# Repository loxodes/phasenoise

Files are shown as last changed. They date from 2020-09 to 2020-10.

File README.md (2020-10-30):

# low(ish) phase noise downconverter 
* 10-6000 MHz RF
* DC-1MHz IF
* Internal LO generation, phase locked to RF input
* Designed to fit on the J40 header of Lattice ECP5 EVN eval board

Software development and hardware testing is in progress.
The only documentation is the [schematic](./phase_noise_downconver_schematic_2020_10.pdf).

## Usage
This project is under development, y'all probably don't want to try reproducing it yet.

## License
Unless otherwise noted, all work is under a MIT license.

## Contact
Feel free to contact me at arcticmicrowave@gmail.com or loxodes on irc.freenode.net

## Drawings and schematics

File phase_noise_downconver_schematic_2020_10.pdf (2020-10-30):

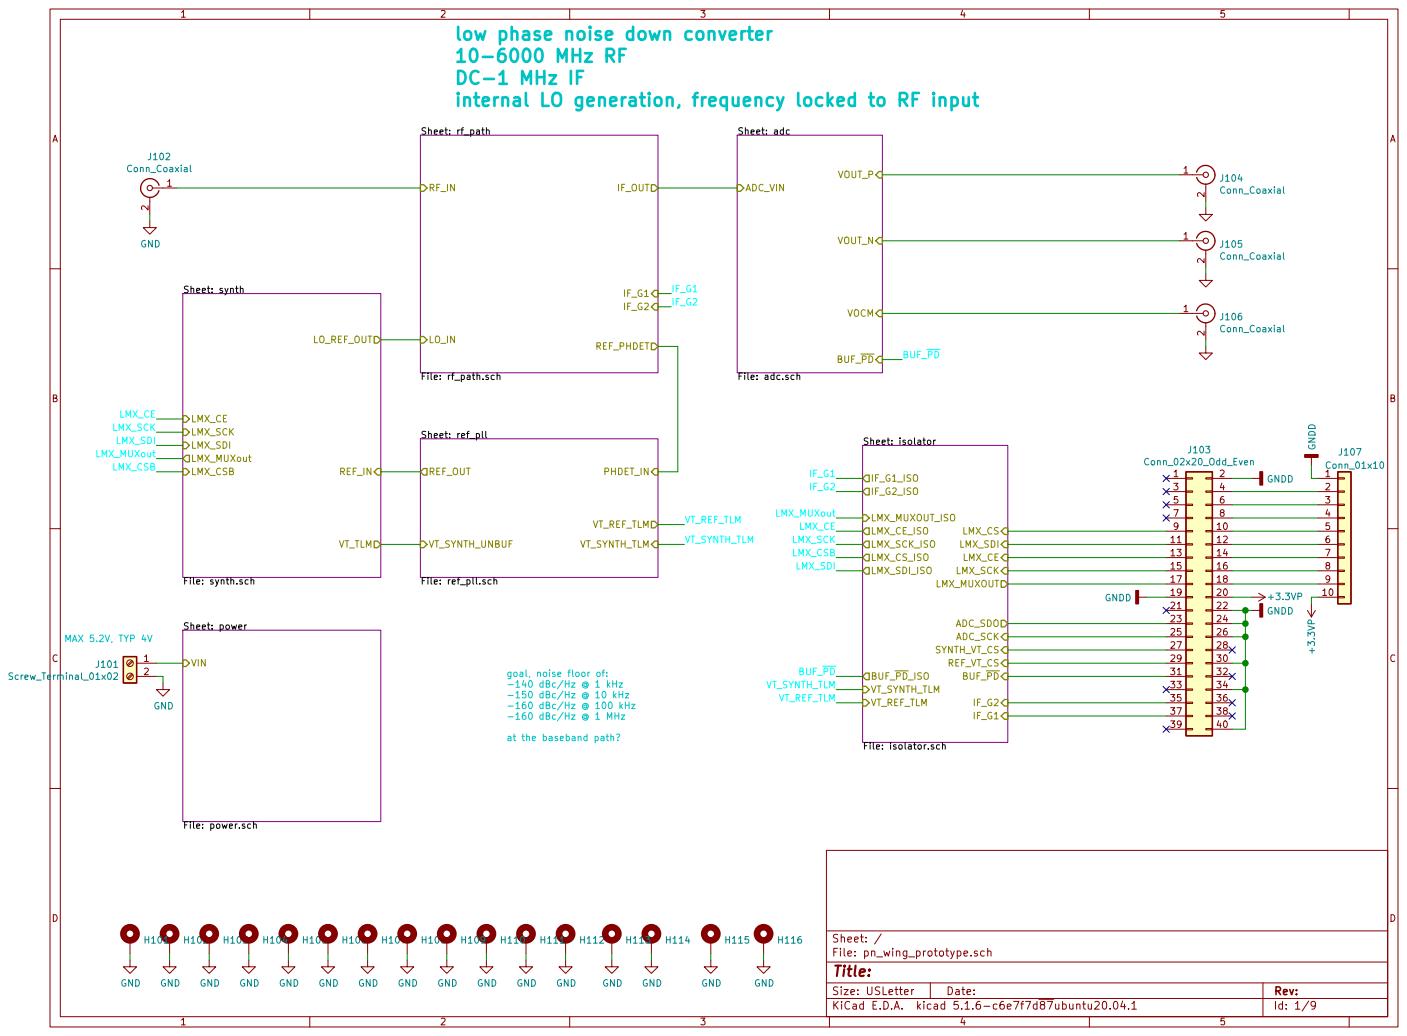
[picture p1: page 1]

low phase noise down converter
10-6000 MHz RF
DC-1 MHz IF

internal LO generation, frequency locked to RF input MAX 5.2V, TYP 4V

Sheet: adc File: adc.sch ADC_VIN

11 | 12 6
13 | 14 7
15 | 16 8
17 | 18 9

File: pn_wing_prototype.sch Sheet: / Sheet: power
File: power.sch VIN

25 | 26
27 | 28 30

goal, noise floor of: -140 dBc/Hz @ 1 kHz

-150 dBc/Hz @ 10 kHz
-160 dBc/Hz @ 100 kHz
-160 dBc/Hz @ 1 MHz at the baseband path?

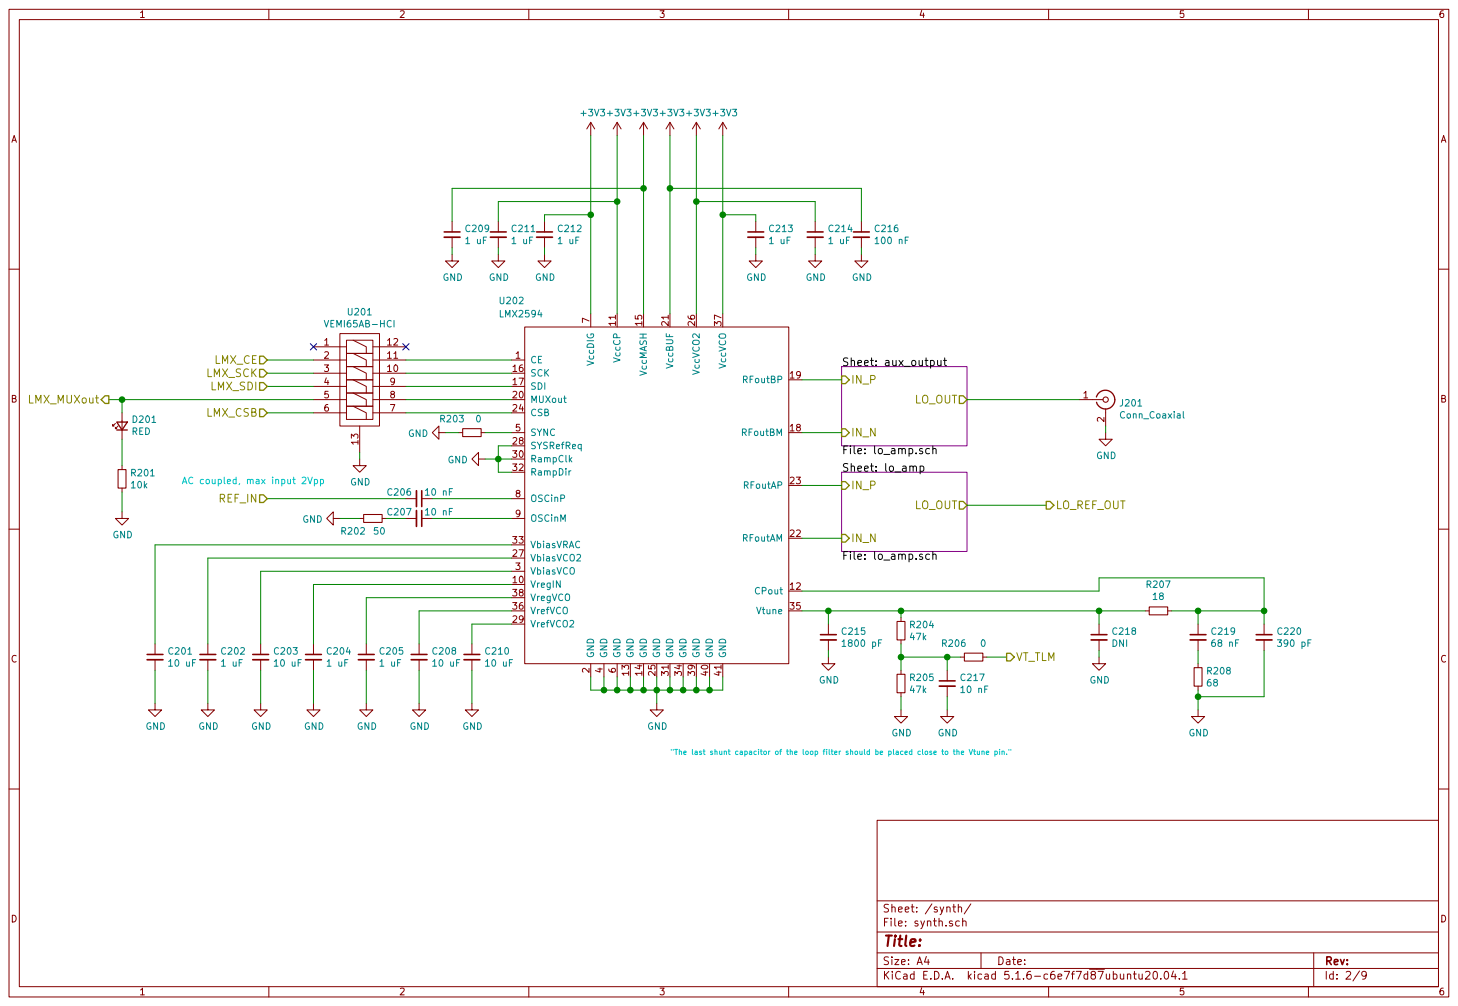
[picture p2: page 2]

2 MUXout 20 VccBUF 21 RFoutAM 22 RFoutAP 23 CSB 24 GND 25 VccVCO2 26 VbiasVCO2 27 SYSRefReq 28 VrefVCO2 29 VbiasVCO 3 RampClk 30 GND 31 RampDir 32 VbiasVRAC 33 GND 34 Vtune 35 VrefVCO 36 VccVCO 37

4 GND 40 GND 41 SYNC 5 GND

AC coupled, max input 2Vpp

"The last shunt capacitor of the loop filter should be placed close to the Vtune pin."

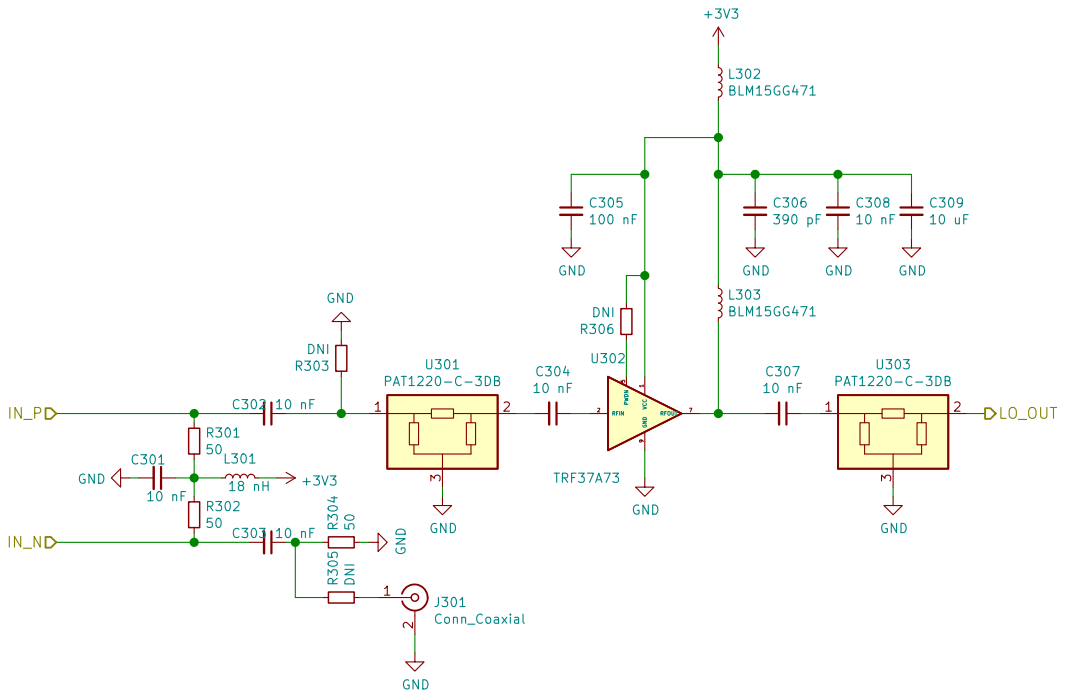
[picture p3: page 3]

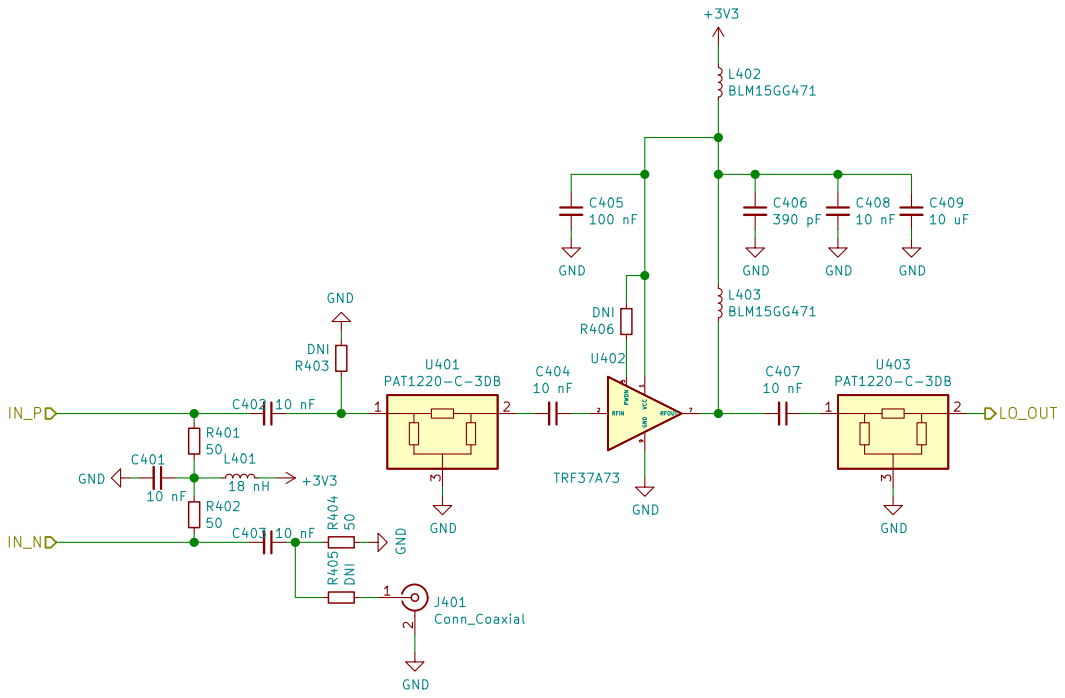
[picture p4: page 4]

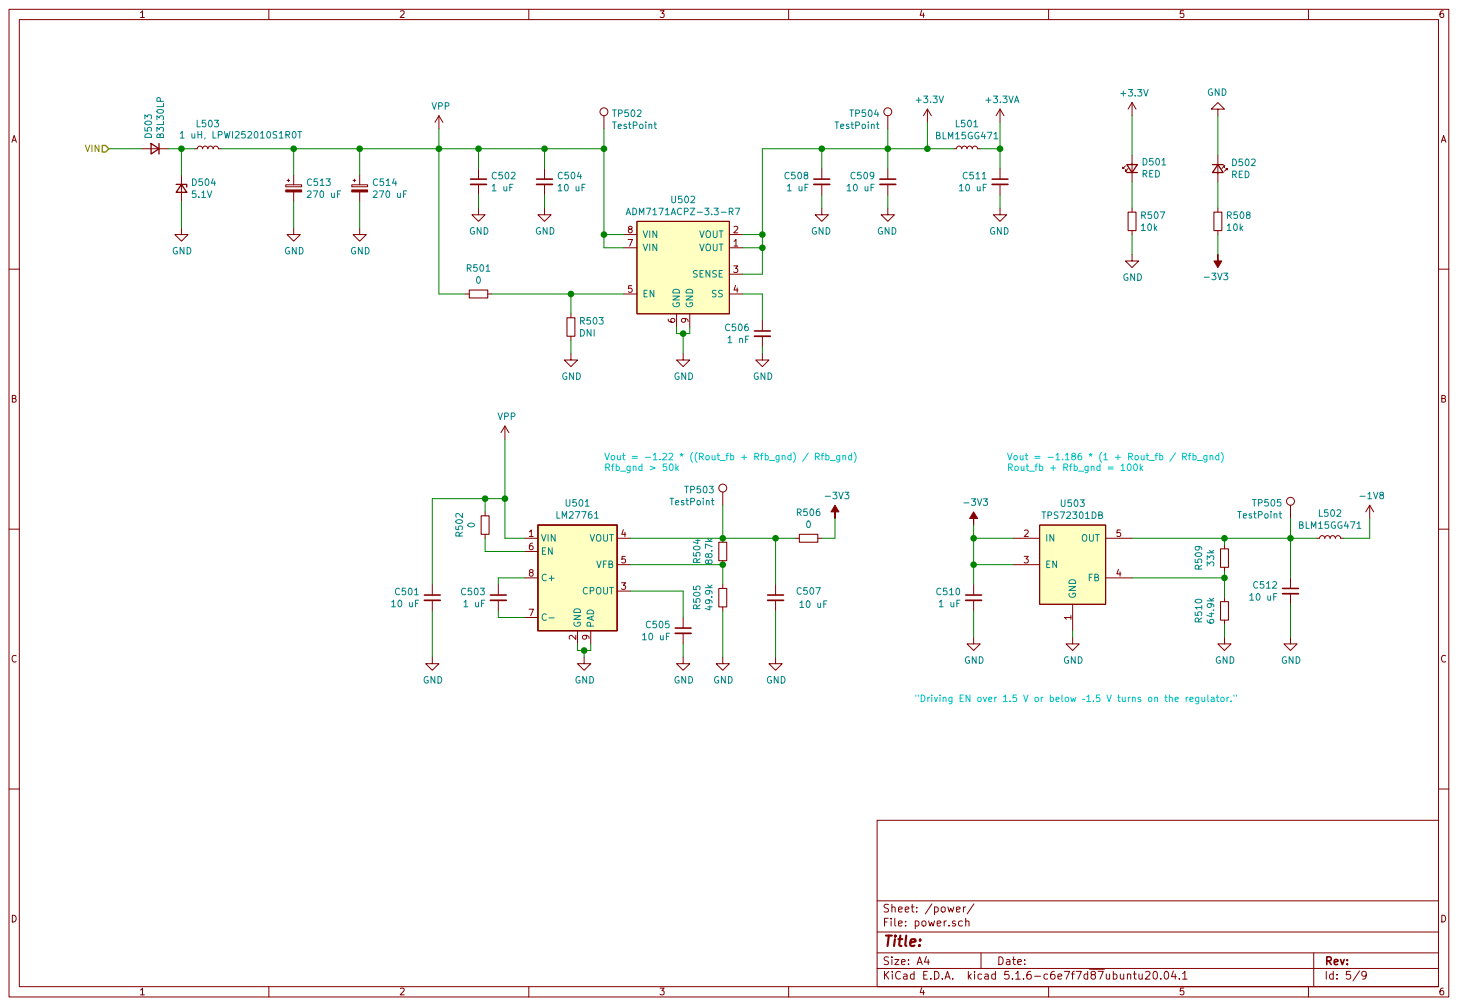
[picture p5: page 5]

2 CPOUT 3 VOUT 4 VFB 5 EN 6 C- 7 C+ 8 PAD

"Driving EN over 1.5 V or below 1.5 V turns on the regulator."

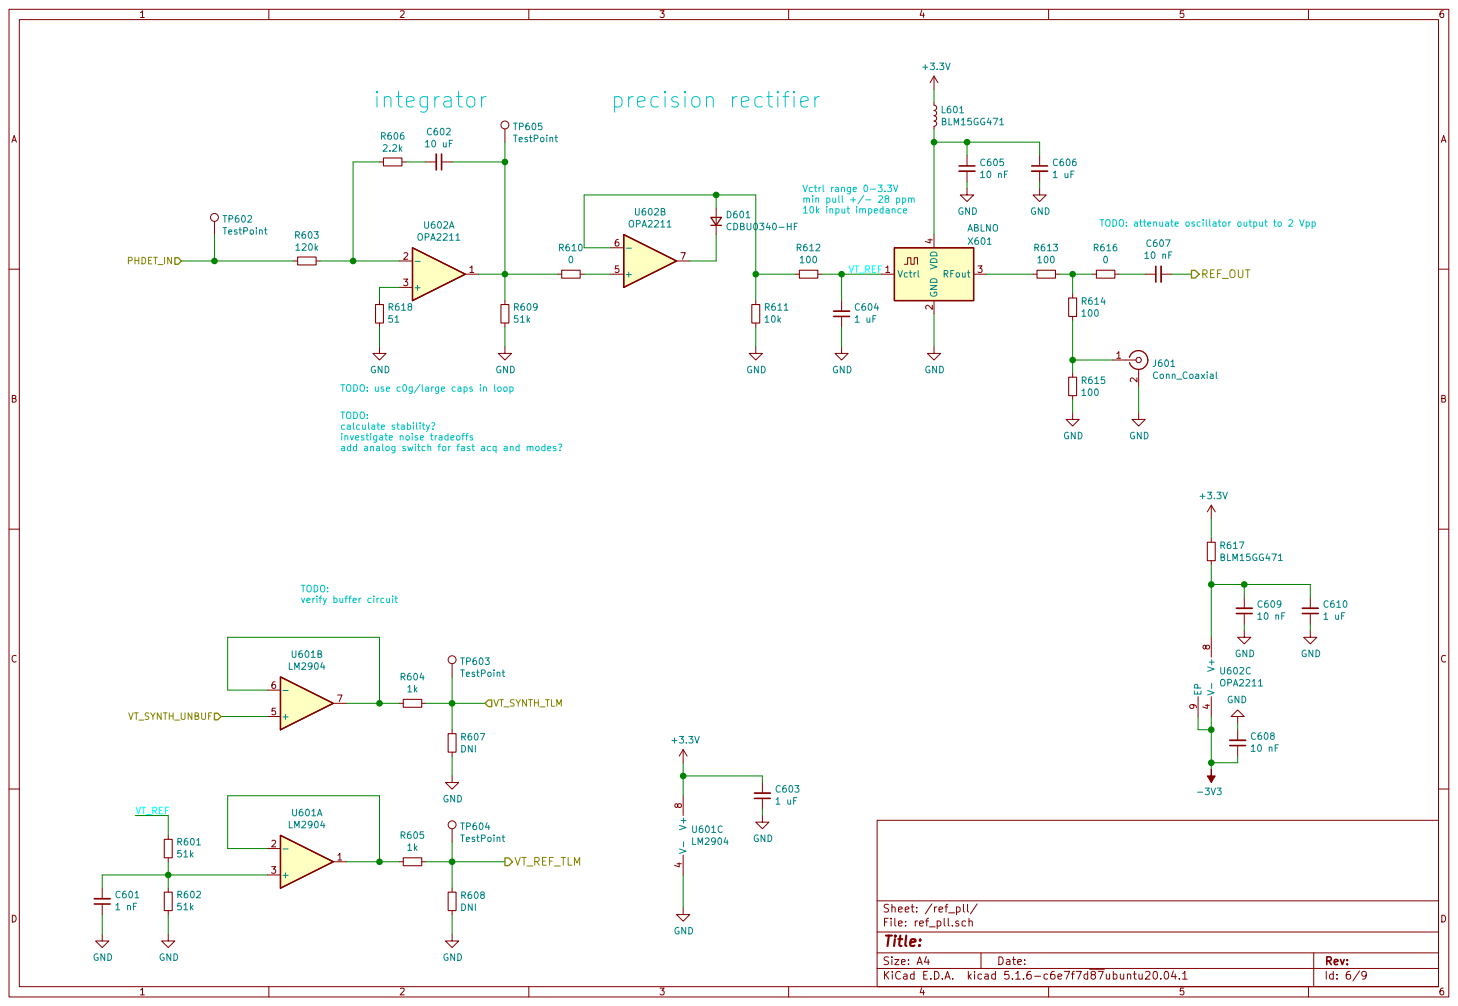
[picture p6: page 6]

10k input impedance TODO: verify buffer circuit TODO: calculate stability?

TODO: attenuate oscillator output to 2 Vpp

TODO: use c0g/large caps in loop

investigate noise tradeoffs
add analog switch for fast acq and modes?

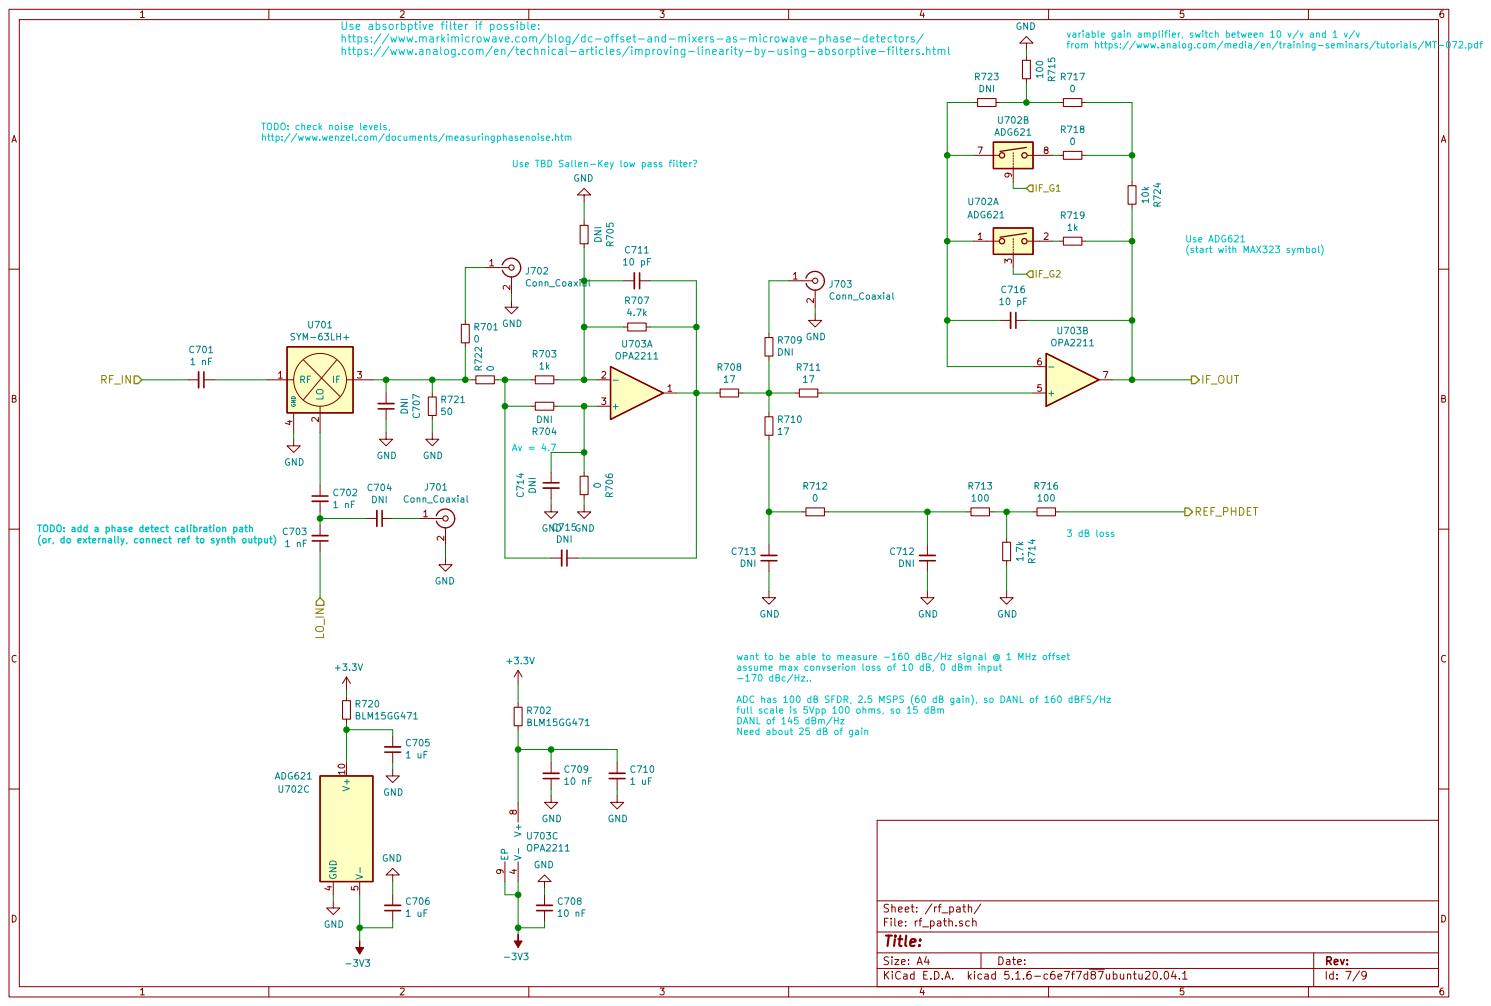
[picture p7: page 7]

IF_G2 Use absorbptive filter if possible:
https://www.markimicrowave.com/blog/dc-offset-and-mixers-as-microwave-phase-detectors/

variable gain amplifier, switch between 10 v/v and 1 v/v

https://www.analog.com/en/technical-articles/improving-linearity-by-using-absorptive-filters.html TODO: check noise levels, http://www.wenzel.com/documents/measuringphasenoise.htm

Use TBD Sallen-Key low pass filter?

DANL of 145 dBm/Hz Need about 25 dB of gain Av = 4.7

TODO: add a phase detect calibration path
(or, do externally, connect ref to synth output)

want to be able to measure -160 dBc/Hz signal @ 1 MHz offset
assume max convserion loss of 10 dB, 0 dBm input -170 dBc/Hz.. ADC has 100 dB SFDR, 2.5 MSPS (60 dB gain), so DANL of 160 dBFS/Hz

full scale is 5Vpp 100 ohms, so 15 dBm

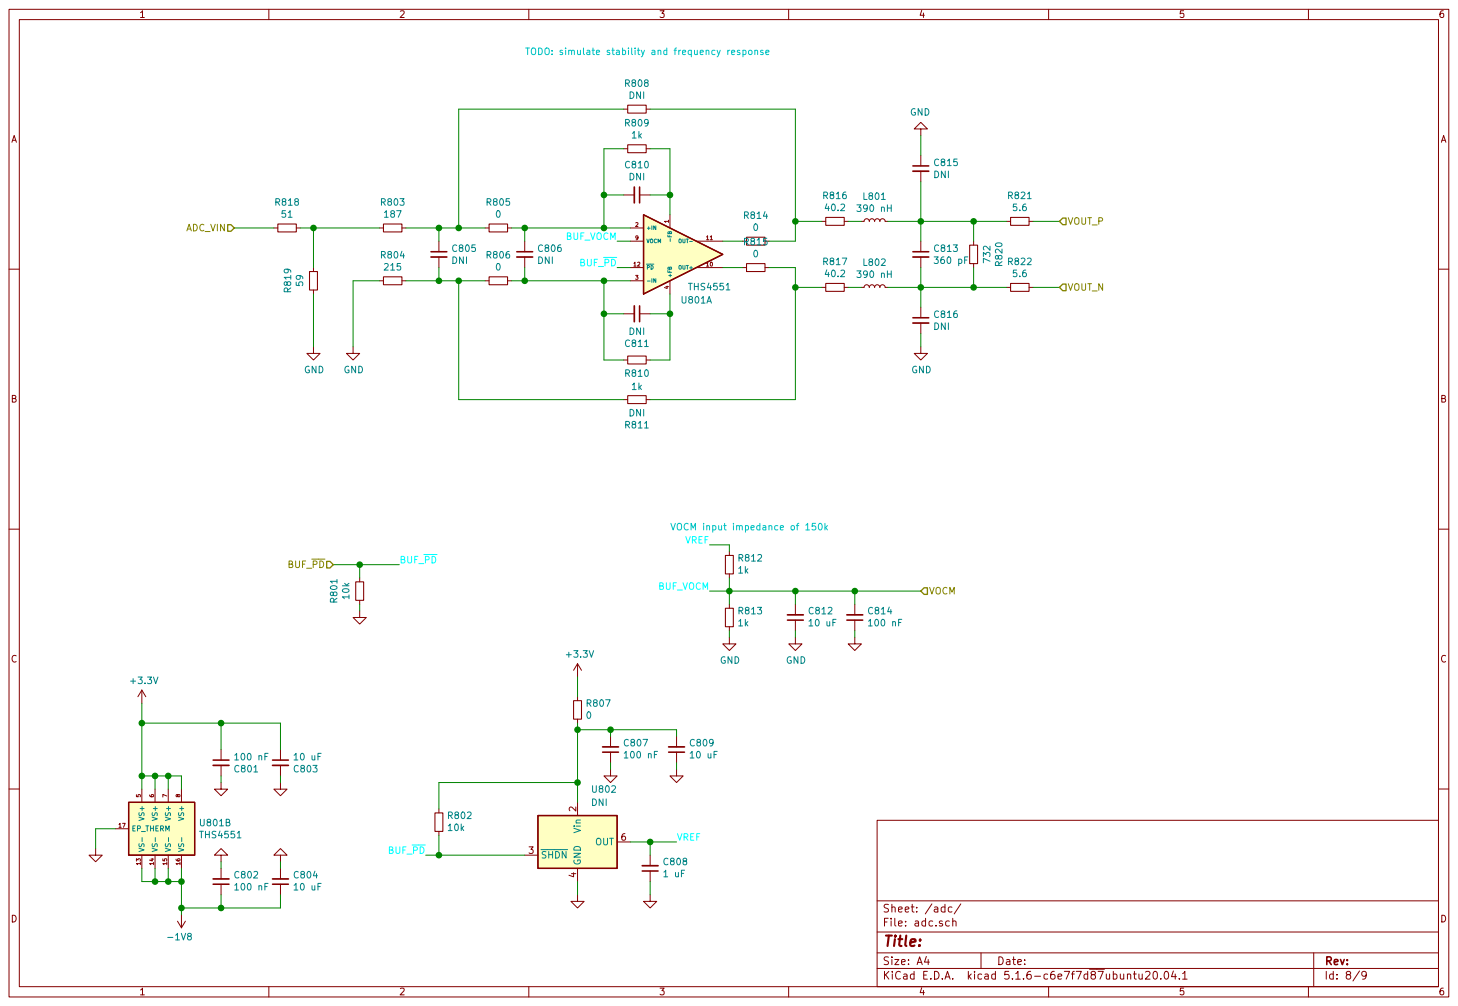
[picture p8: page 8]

TODO: simulate stability and frequency response
1 uF R811 DNI C811 DNI R804

VOCM input impedance of 150k

Id: 8/9 Title: File: adc.sch Sheet: /adc/

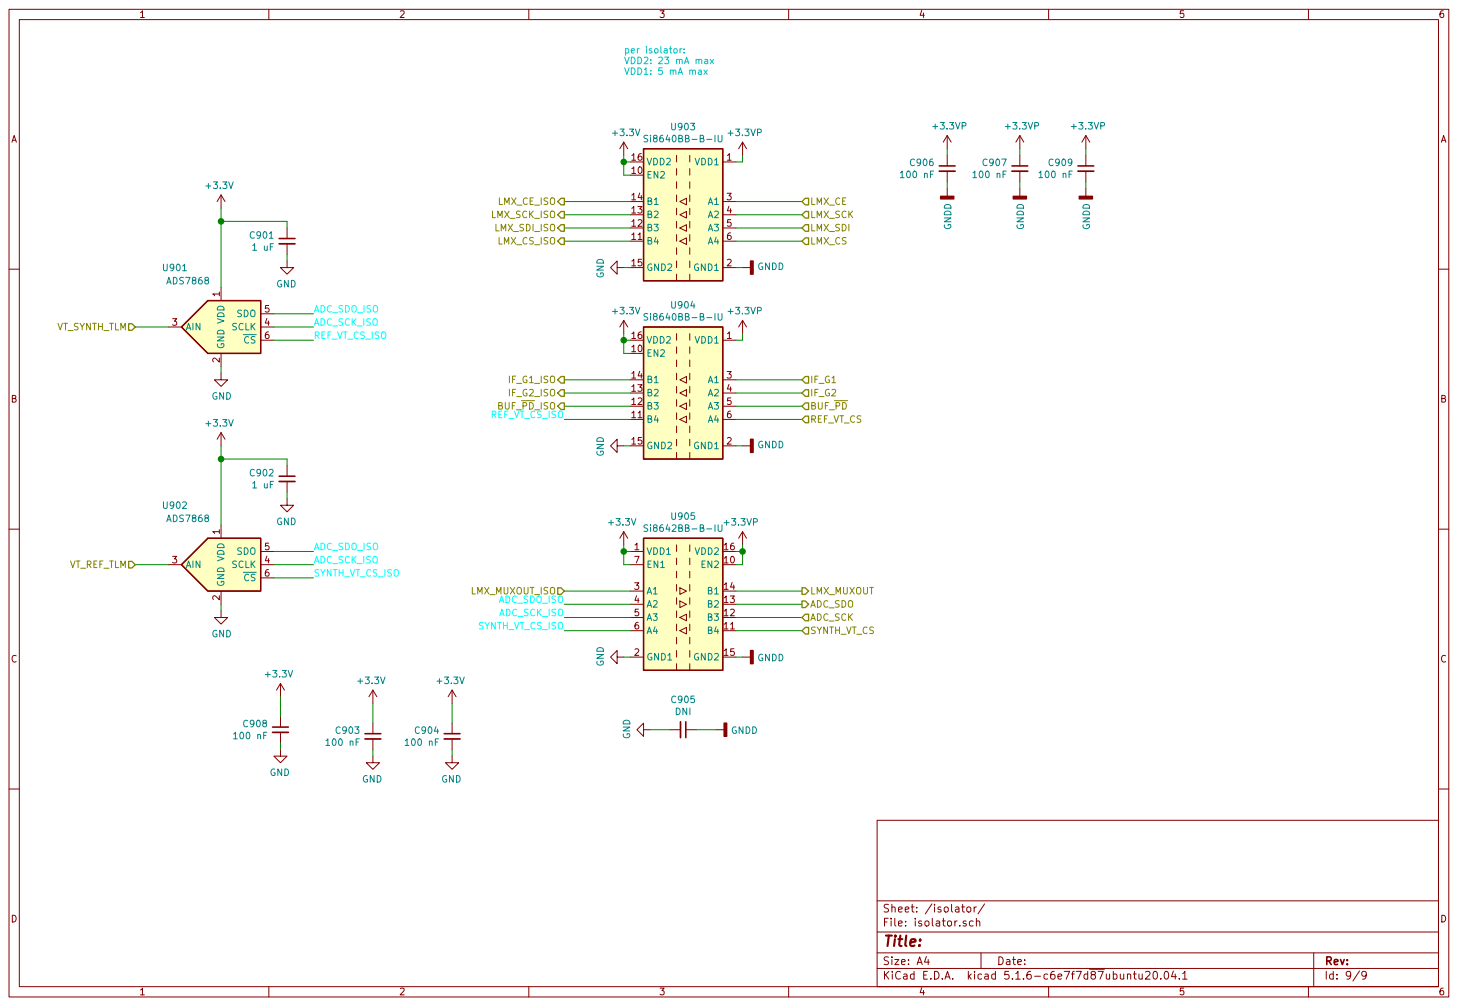
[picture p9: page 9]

per isolator: VDD2: 23 mA max VDD1: 5 mA max
100 nF VDD

2 AIN 3 SCLK 4 SDO 5 CS 6 U901 ADS7868 GND

2 AIN 3 SCLK 4 SDO 5 CS 6 U902 ADS7868 GND GND

Id: 9/9 Title: File: isolator.sch Sheet: /isolator/ GND

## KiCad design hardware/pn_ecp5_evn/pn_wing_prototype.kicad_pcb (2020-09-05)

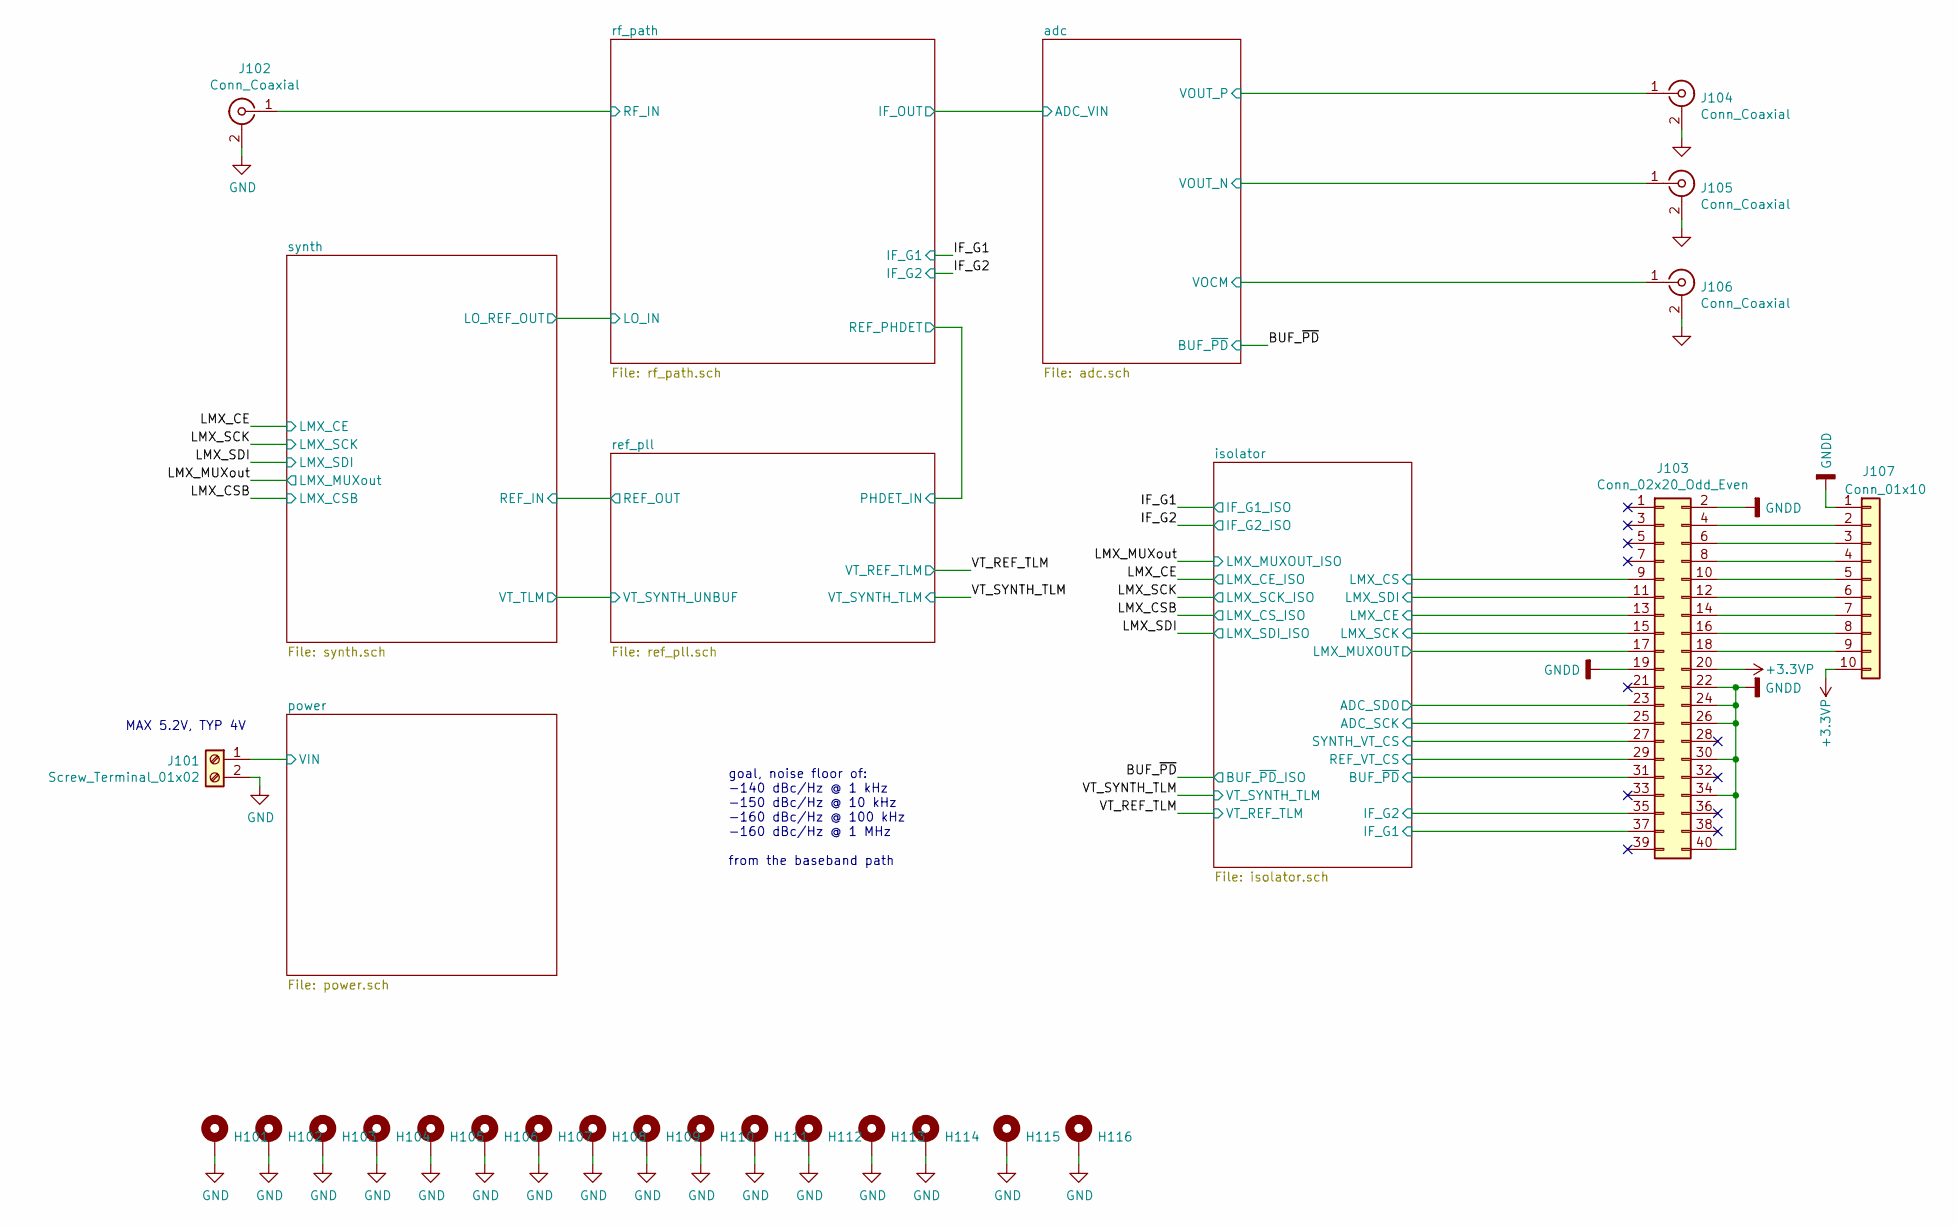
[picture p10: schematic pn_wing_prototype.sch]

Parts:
H101, H102, H103, H104, H105, H106, H107, H108, H109, H110, H111, H112, H113, H114, H115, H116: MountingHole_Pad; MountingHole_2.7mm_M2.5_ISO14580_Pad
J101: Screw_Terminal_01x02; TerminalBlock_Phoenix_MPT-0,5-2-2.54_1x02_P2.54mm_Horizontal
J102, J104, J105, J106: Conn_Coaxial; SMA_Molex_73251-1153_OSHFR408
J103: Conn_02x20_Odd_Even; PinSocket_2x20_P2.54mm_Vertical
J107: Conn_01x10; PinHeader_1x10_P2.54mm_Vertical

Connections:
+3.3VP: J103.20, J107.10; also elsewhere on the board
/adc/VOCM: J106.1 (In); also elsewhere on the board
/adc/VOUT_N: J105.1 (In); also elsewhere on the board
/adc/VOUT_P: J104.1 (In); also elsewhere on the board
/isolator/ADC_SCK: J103.25; also elsewhere on the board
/isolator/ADC_SDO: J103.23; also elsewhere on the board
/isolator/BUF_~PD: J103.31; also elsewhere on the board
/isolator/IF_G1: J103.37; also elsewhere on the board
/isolator/IF_G2: J103.35; also elsewhere on the board
/isolator/LMX_CE: J103.13; also elsewhere on the board
/isolator/LMX_CS: J103.9; also elsewhere on the board
/isolator/LMX_MUXOUT: J103.17; also elsewhere on the board
/isolator/LMX_SCK: J103.15; also elsewhere on the board
/isolator/LMX_SDI: J103.11; also elsewhere on the board
/isolator/REF_VT_CS: J103.29; also elsewhere on the board
/isolator/SYNTH_VT_CS: J103.27; also elsewhere on the board
/power/VIN: J101.1; also elsewhere on the board
/rf_path/RF_IN: J102.1 (In); also elsewhere on the board
GND: H101.1, H102.1, H103.1, H104.1, H105.1, H106.1, H107.1, H108.1, H109.1, H110.1, H111.1, H112.1, H113.1, H114.1, H115.1, H116.1, J101.2, J102.2 (Ext), J104.2 (Ext), J105.2 (Ext), J106.2 (Ext); also elsewhere on the board
GNDD: J103.2, J103.19, J103.22, J103.24, J103.26, J103.30, J103.34, J103.40, J107.1; also elsewhere on the board
unnamed: J103.4, J107.2
unnamed: J103.6, J107.3
unnamed: J103.8, J107.4
unnamed: J103.10, J107.5
unnamed: J103.12, J107.6
unnamed: J103.14, J107.7
unnamed: J103.16, J107.8
unnamed: J103.18, J107.9

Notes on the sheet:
goal, noise floor of: -140 dBc/Hz @ 1 kHz -150 dBc/Hz @ 10 kHz -160 dBc/Hz @ 100 kHz -160 dBc/Hz @ 1 MHz from the baseband path
MAX 5.2V, TYP 4V

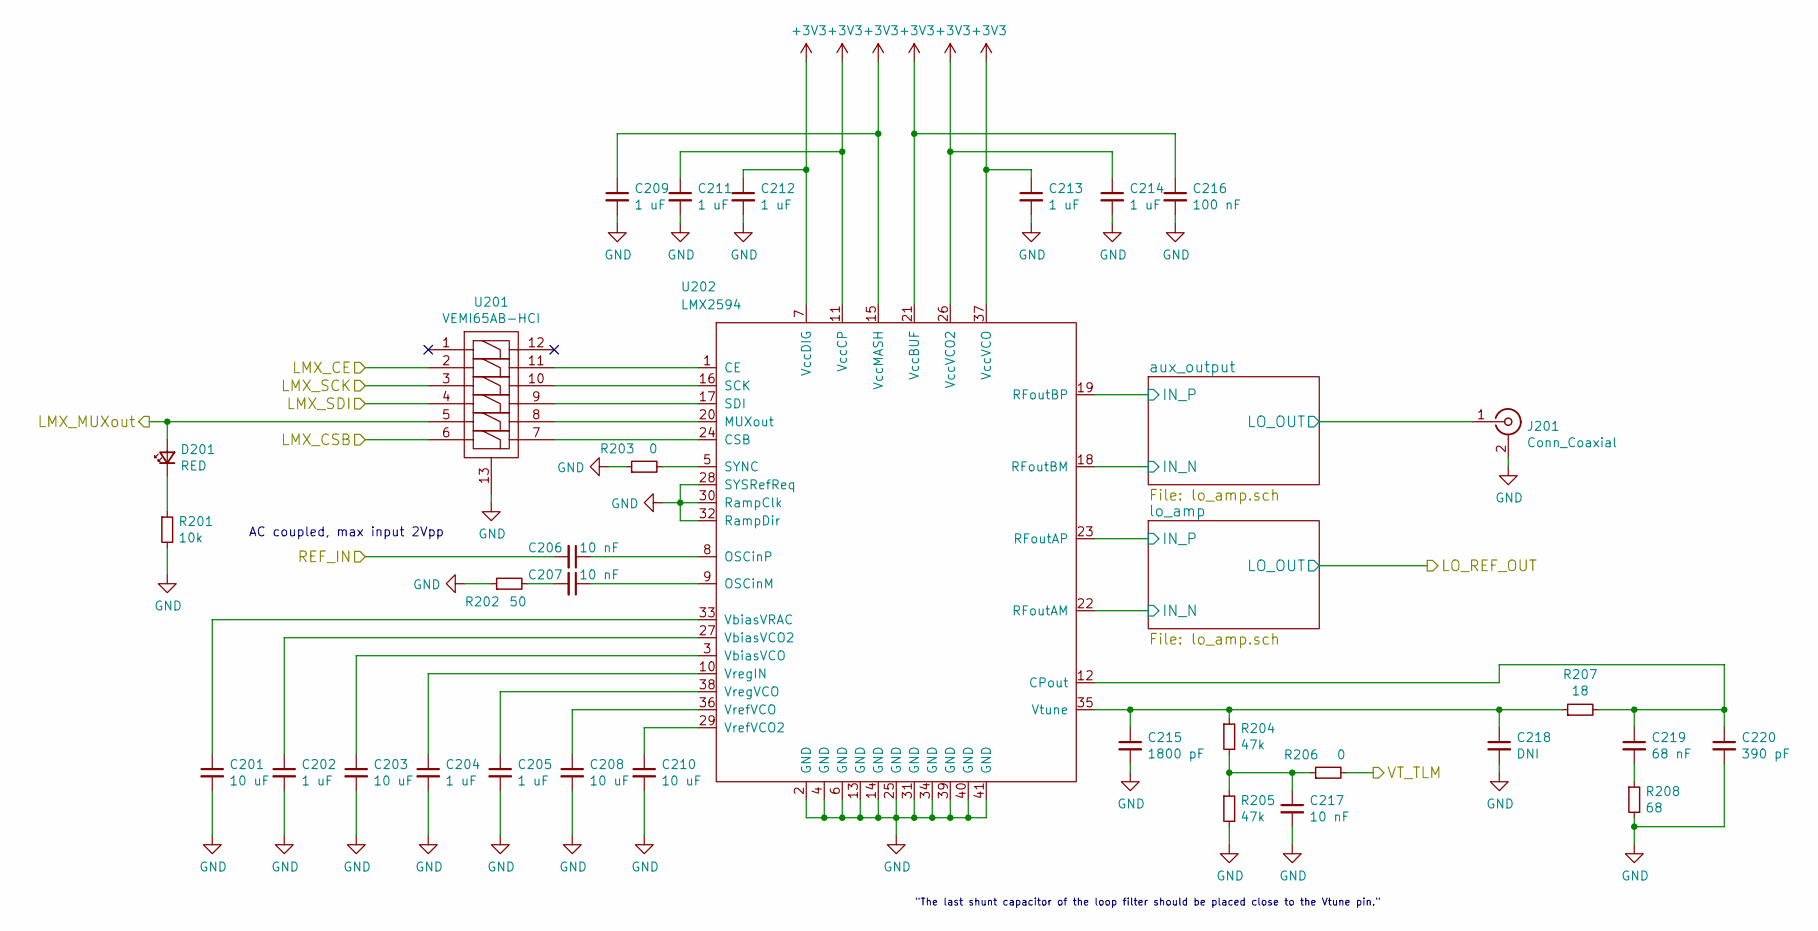
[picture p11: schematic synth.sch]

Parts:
C201, C203, C208, C210: 10 uF; C_0603_1608Metric
C202, C204, C205, C209, C211, C212, C213, C214: 1 uF; C_0402_1005Metric
C206, C207, C217: 10 nF; C_0402_1005Metric
C215: 1800 pF; C_0402_1005Metric
C216: 100 nF; C_0402_1005Metric
C218: DNI; C_0603_1608Metric
C219: 68 nF; C_0603_1608Metric
C220: 390 pF; C_0603_1608Metric
D201: RED; LED_0603_1608Metric
J201: Conn_Coaxial; SMA_Molex_73251-1153_OSHFR408
R201: 10k; R_0402_1005Metric
R202: 50; R_0402_1005Metric
R203, R206: 0; R_0402_1005Metric
R204, R205: 47k; R_0402_1005Metric
R207: 18; R_0402_1005Metric
R208: 68; R_0402_1005Metric
U201: VEMI65AB-HCI; LLP2513-13L
U202: LMX2594; Texas_S-PVQFN-N40_EP4.6x4.6mm

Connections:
/LMX_CE: U201.2; also elsewhere on the board
/LMX_CSB: U201.6; also elsewhere on the board
/LMX_MUXout: D201.2 (A), U201.5; also elsewhere on the board
/LMX_SCK: U201.3; also elsewhere on the board
/LMX_SDI: U201.4; also elsewhere on the board
/ref_pll/VT_SYNTH_UNBUF: R206.2; also elsewhere on the board
/synth/REF_IN: C206.2; also elsewhere on the board
/synth/aux_output/IN_N: U202.18 (RFoutBM); also elsewhere on the board
/synth/aux_output/IN_P: U202.19 (RFoutBP); also elsewhere on the board
/synth/aux_output/LO_OUT: J201.1 (In); also elsewhere on the board
/synth/lo_amp/IN_N: U202.22 (RFoutAM); also elsewhere on the board
/synth/lo_amp/IN_P: U202.23 (RFoutAP); also elsewhere on the board
GND: C201.2, C202.2, C203.2, C204.2, C205.2, C208.2, C209.2, C210.2, C211.2, C212.2, C213.2, C214.2, C215.2, C216.2, C217.2, C218.2, C220.2, J201.2 (Ext), R201.2, R202.1, R203.1, R205.2, R208.2, U201.13, U202.2 (GND), U202.4 (GND), U202.6 (GND), U202.13 (GND), U202.14 (GND), U202.25 (GND), U202.28 (SYSRefReq), U202.30 (RampClk), U202.31 (GND), U202.32 (RampDir), U202.34 (GND), U202.39 (GND), U202.40 (GND), U202.41 (GND); also elsewhere on the board
unnamed: C201.1, U202.33 (VbiasVRAC)
unnamed: C202.1, U202.27 (VbiasVCO2)
unnamed: C203.1, U202.3 (VbiasVCO)
unnamed: C204.1, U202.10 (VregIN)
unnamed: C205.1, U202.38 (VregVCO)
unnamed: C206.1, U202.8 (OSCinP)
unnamed: C207.1, U202.9 (OSCinM)
unnamed: C207.2, R202.2
unnamed: C208.1, U202.36 (VrefVCO)
unnamed: C210.1, U202.29 (VrefVCO2)
unnamed: C215.1, C218.1, R204.1, R207.1, U202.35 (Vtune)
unnamed: C217.1, R204.2, R205.1, R206.1
unnamed: C219.1, C220.1, R207.2, U202.12 (CPout)
unnamed: C219.2, R208.1
unnamed: D201.1 (K), R201.1
unnamed: R203.2, U202.5 (SYNC)
unnamed: U201.7, U202.24 (CSB)
unnamed: U201.8, U202.20 (MUXout)
unnamed: U201.9, U202.17 (SDI)
unnamed: U201.10, U202.16 (SCK)
unnamed: U201.11, U202.1 (CE)

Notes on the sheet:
"The last shunt capacitor of the loop filter should be placed close to the Vtune pin."
AC coupled, max input 2Vpp

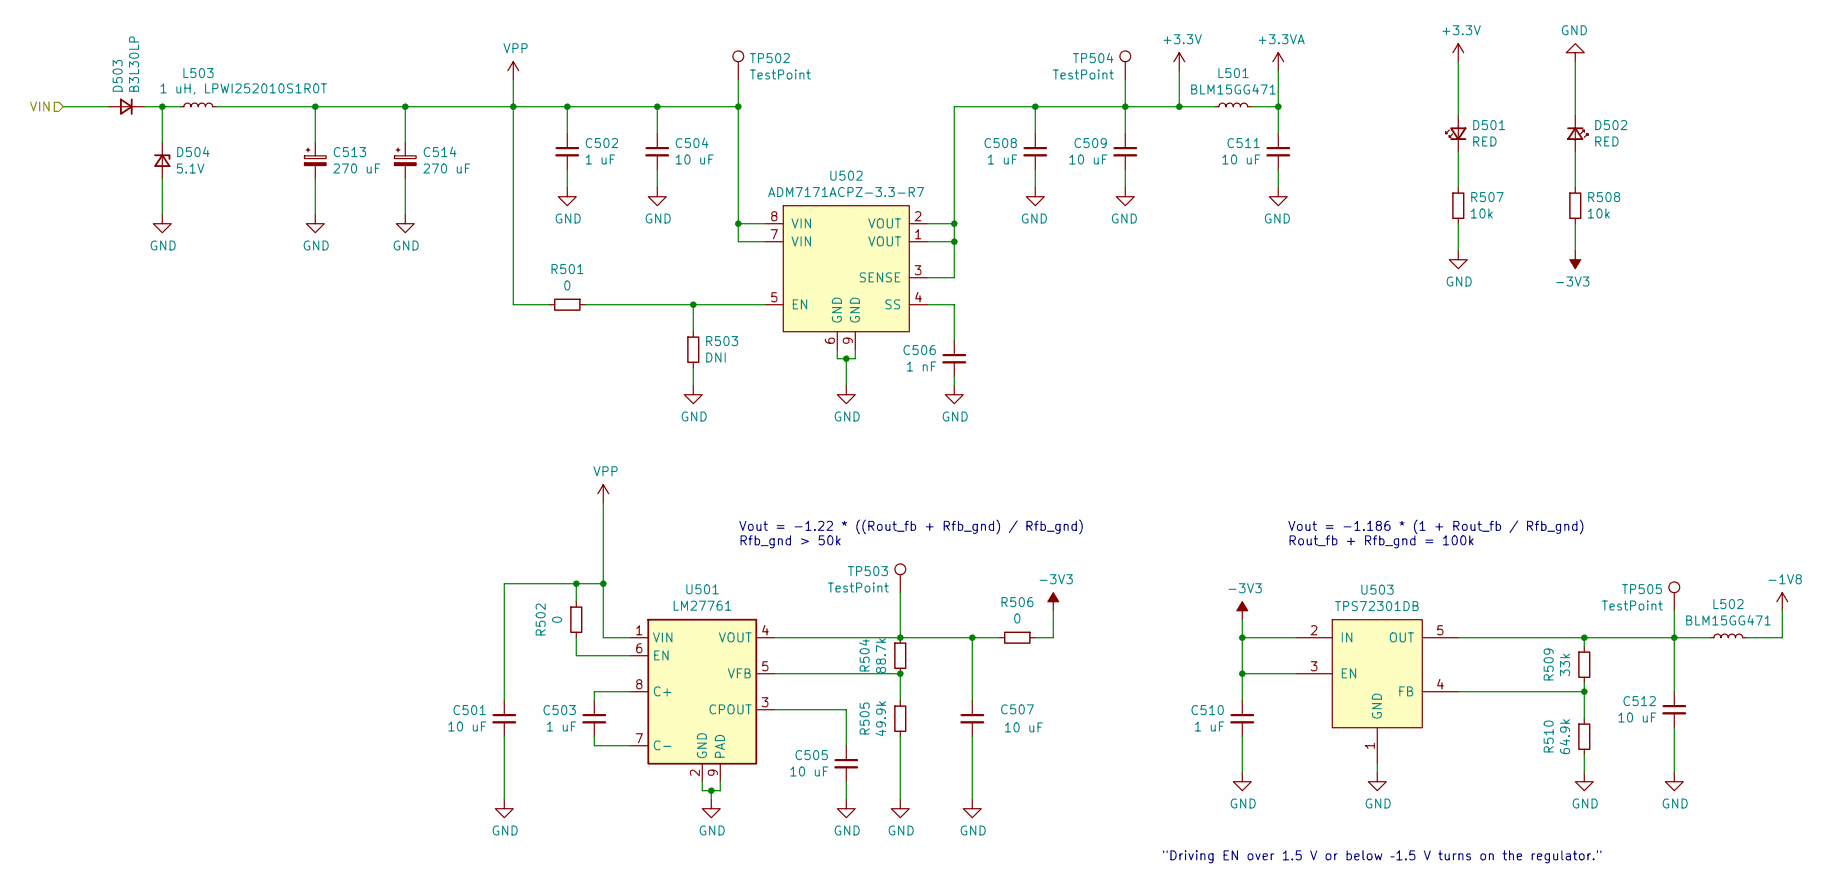
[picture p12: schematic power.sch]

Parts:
C501, C504, C505, C507, C509, C511, C512: 10 uF; C_0603_1608Metric
C502, C503, C508, C510: 1 uF; C_0402_1005Metric
C506: 1 nF; C_0402_1005Metric
C513, C514: 270 uF; CP_Elec_6.3x5.9; MPN 875105245014
D501, D502: RED; LED_0603_1608Metric
D503: B3L30LP; AP02002_DFN8_DIODE
D504: 5.1V; D_SOD-323
L501, L502: BLM15GG471; L_0402_1005Metric
L503: 1 uH, LPWI252010S1R0T; L_1008_2520Metric
R501, R502, R506: 0; R_0402_1005Metric
R503: DNI; R_0402_1005Metric
R504: 88.7k; R_0402_1005Metric
R505: 49.9k; R_0402_1005Metric
R507, R508: 10k; R_0402_1005Metric
R509: 33k; R_0402_1005Metric
R510: 64.9k; R_0402_1005Metric
TP502, TP503, TP504, TP505: TestPoint; TestPoint_Keystone_5015_Micro-Minature
U501: LM27761; WSON-8-1EP_2x2mm_P0.5mm_EP0.9x1.6mm
U502: ADM7171ACPZ-3.3-R7; DFN-8-1EP_3x3mm_P0.5mm_EP1.66x2.38mm
U503: TPS72301DB; SOT-23-5

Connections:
+3.3VA: C511.1, L501.2
-1V8: L502.2; also elsewhere on the board
-3V3: C510.1, R506.1, R508.2, U503.2 (IN), U503.3 (EN); also elsewhere on the board
/power/VIN: D503.2 (A); also elsewhere on the board
GND: C501.2, C502.2, C504.2, C505.2, C506.2, C507.2, C508.2, C509.2, C510.2, C511.2, C512.2, C513.2, C514.2, D502.1 (K), D504.2 (A), R503.2, R505.2, R507.2, R510.2, U501.2 (GND), U501.9 (PAD), U502.6 (GND), U502.9 (GND), U503.1 (GND); also elsewhere on the board
unnamed: C503.1, U501.8 (C+)
unnamed: C503.2, U501.7 (C-)
unnamed: C505.1, U501.3 (CPOUT)
unnamed: C506.1, U502.4 (SS)
unnamed: C507.1, R504.1, R506.2, TP503.1, U501.4 (VOUT)
unnamed: C512.1, L502.1, R509.1, TP505.1, U503.5 (OUT)
unnamed: D501.1 (K), R507.1
unnamed: D502.2 (A), R508.1
unnamed: D503.1 (K), D504.1 (K), L503.1
unnamed: R501.1, R503.1, U502.5 (EN)
unnamed: R502.2, U501.6 (EN)
unnamed: R504.2, R505.1, U501.5 (VFB)
unnamed: R509.2, R510.1, U503.4 (FB)
VPP: C501.1, C502.1, C504.1, C513.1, C514.1, L503.2, R501.2, R502.1, TP502.1, U501.1 (VIN), U502.7 (VIN), U502.8 (VIN)

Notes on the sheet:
Vout = -1.186 * (1 + Rout_fb / Rfb_gnd) Rout_fb + Rfb_gnd = 100k
Vout = -1.22 * ((Rout_fb + Rfb_gnd) / Rfb_gnd) Rfb_gnd > 50k
"Driving EN over 1.5 V or below –1.5 V turns on the regulator."

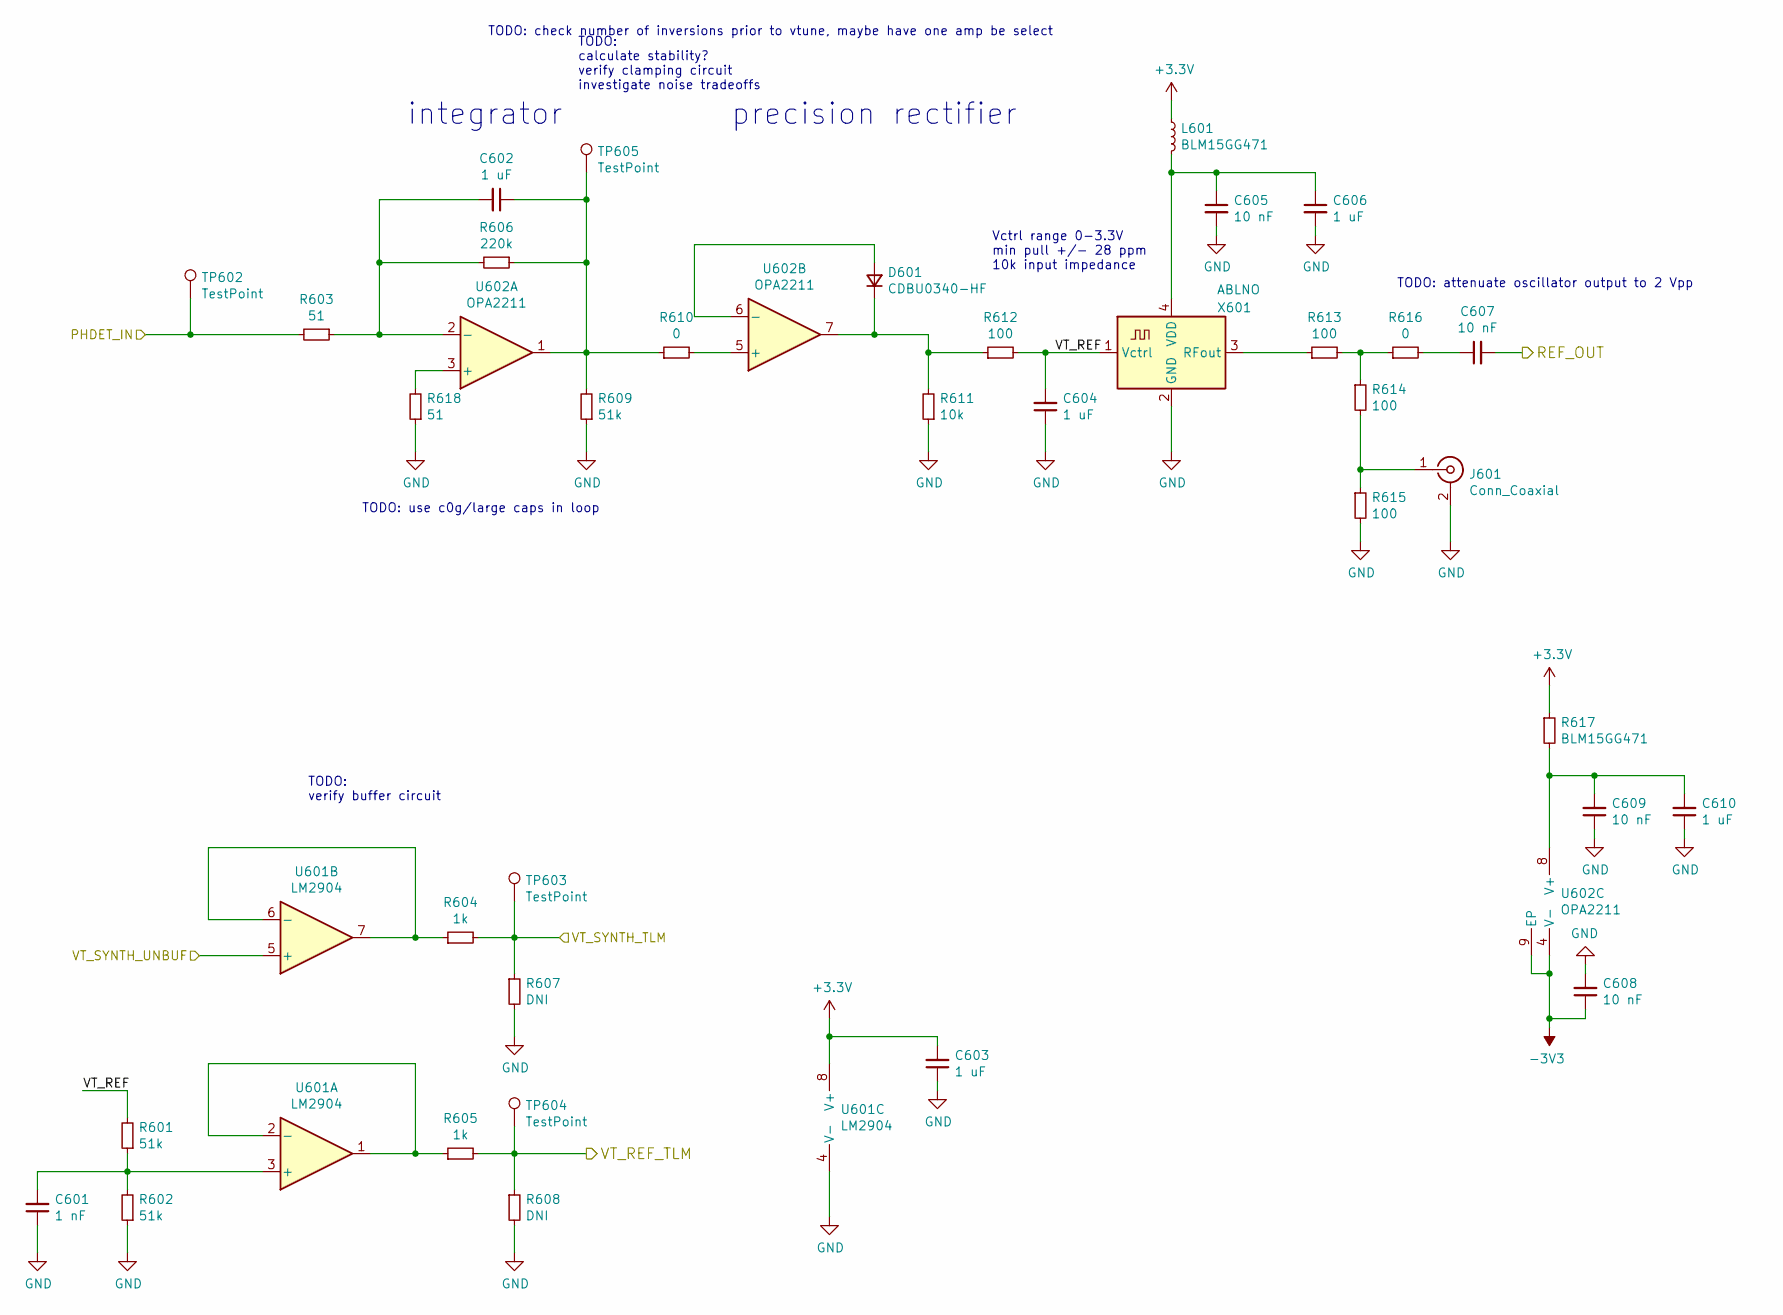
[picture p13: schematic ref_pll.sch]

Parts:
C601: 1 nF; C_0402_1005Metric
C602, C604: 1 uF; C_0603_1608Metric
C603, C606, C610: 1 uF; C_0402_1005Metric
C605, C607, C608, C609: 10 nF; C_0402_1005Metric
D601: CDBU0340-HF; D_0603_1608Metric
J601: Conn_Coaxial; U.FL_Hirose_U.FL-R-SMT-1_Vertical
L601: BLM15GG471; L_0402_1005Metric
R601, R602, R609: 51k; R_0402_1005Metric
R603, R618: 51; R_0402_1005Metric
R604, R605: 1k; R_0402_1005Metric
R606: 220k; R_0402_1005Metric
R607, R608: DNI; R_0402_1005Metric
R610, R616: 0; R_0402_1005Metric
R611: 10k; R_0402_1005Metric
R612, R613, R614, R615: 100; R_0402_1005Metric
R617: BLM15GG471; R_0402_1005Metric
TP602, TP603, TP604, TP605: TestPoint; TestPoint_Keystone_5015_Micro-Minature
U601: LM2904; MSOP-8_3x3mm_P0.65mm
U602: OPA2211; SOIC-8-1EP_3.9x4.9mm_P1.27mm_EP2.514x3.2mm
X601: ABLNO; Oscillator_SMD_Abracon_ABLNO

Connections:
-3V3: C608.1, U602.4 (V-), U602.9 (EP); also elsewhere on the board
/VT_REF_TLM: R605.2, R608.1, TP604.1; also elsewhere on the board
/VT_SYNTH_TLM: R604.2, R607.1, TP603.1; also elsewhere on the board
/ref_pll/PHDET_IN: R603.2, TP602.1; also elsewhere on the board
/ref_pll/VT_REF: C604.2, R601.2, R612.2, X601.1 (Vctrl)
/ref_pll/VT_SYNTH_UNBUF: U601.5 (+); also elsewhere on the board
/synth/REF_IN: C607.2; also elsewhere on the board
GND: C601.1, C603.1, C604.1, C605.2, C606.2, C608.2, C609.1, C610.1, J601.2 (Ext), R602.1, R607.2, R608.2, R609.1, R611.1, R615.2, R618.1, U601.4 (V-), X601.2 (GND); also elsewhere on the board
unnamed: C601.2, R601.1, R602.2, U601.3 (+)
unnamed: C602.1, R606.1, R609.2, R610.1, TP605.1, U602.1
unnamed: C602.2, R603.1, R606.2, U602.2 (-)
unnamed: C605.1, C606.1, L601.2, X601.4 (VDD)
unnamed: C607.1, R616.2
unnamed: C609.2, C610.2, R617.2, U602.8 (V+)
unnamed: D601.1 (K), R611.2, R612.1, U602.7
unnamed: D601.2 (A), U602.6 (-)
unnamed: J601.1 (In), R614.2, R615.1
unnamed: R604.1, U601.6 (-), U601.7
unnamed: R605.1, U601.1, U601.2 (-)
unnamed: R610.2, U602.5 (+)
unnamed: R613.1, X601.3 (RFout)
unnamed: R613.2, R614.1, R616.1
unnamed: R618.2, U602.3 (+)

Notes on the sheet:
Vctrl range 0-3.3V min pull +/- 28 ppm 10k input impedance
TODO: calculate stability? verify clamping circuit investigate noise tradeoffs
TODO: verify buffer circuit
TODO: check number of inversions prior to vtune, maybe have one amp be select
integrator
precision rectifier
TODO: attenuate oscillator output to 2 Vpp
TODO: use c0g/large caps in loop

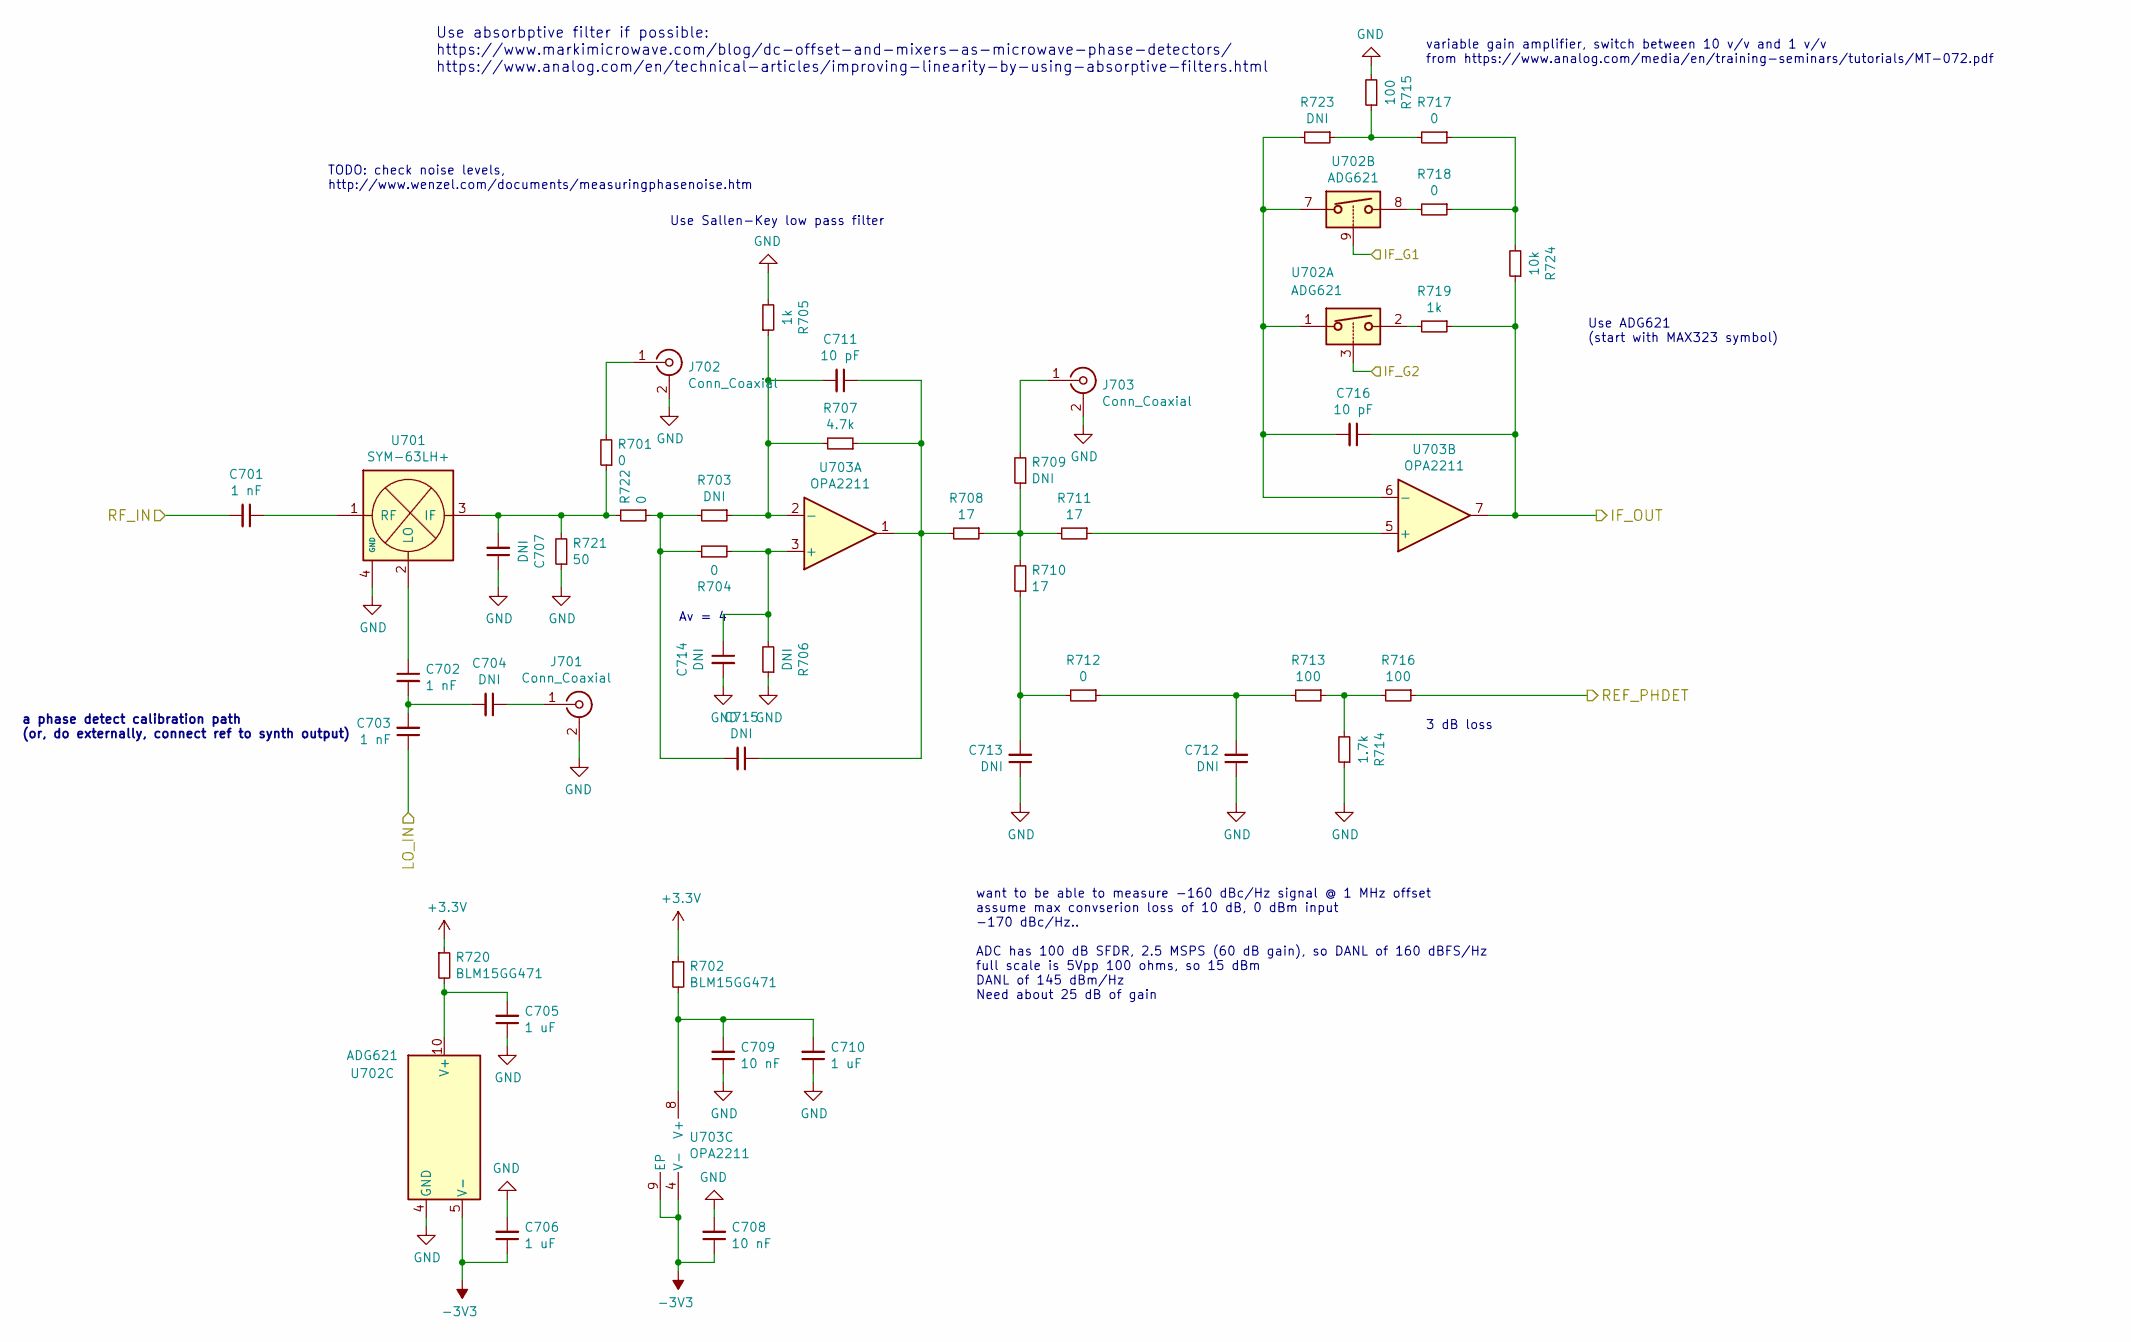
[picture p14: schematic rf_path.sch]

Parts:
C701, C702, C703: 1 nF; C_0402_1005Metric
C704, C707, C712, C713: DNI; C_0402_1005Metric
C705, C706, C710: 1 uF; C_0402_1005Metric
C708, C709: 10 nF; C_0402_1005Metric
C711, C716: 10 pF; C_0603_1608Metric
C714, C715: DNI; C_0603_1608Metric
J701, J702, J703: Conn_Coaxial; U.FL_Hirose_U.FL-R-SMT-1_Vertical
R701, R704, R712, R717, R718, R722: 0; R_0402_1005Metric
R702, R720: BLM15GG471; R_0402_1005Metric
R703, R706, R709, R723: DNI; R_0402_1005Metric
R705, R719: 1k; R_0402_1005Metric
R707: 4.7k; R_0402_1005Metric
R708, R710, R711: 17; R_0402_1005Metric
R713, R715, R716: 100; R_0402_1005Metric
R714: 1.7k; R_0402_1005Metric
R721: 50; R_0402_1005Metric
R724: 10k; R_0402_1005Metric
U701: SYM-63LH+; Mini-Circuits_TTT167
U702: ADG621; MSOP-10_3x3mm_P0.5mm
U703: OPA2211; SOIC-8-1EP_3.9x4.9mm_P1.27mm_EP2.514x3.2mm

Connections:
-3V3: C706.1, C708.1, U702.5 (V-), U703.4 (V-), U703.9 (EP); also elsewhere on the board
/IF_G1: U702.9; also elsewhere on the board
/IF_G2: U702.3; also elsewhere on the board
/adc/ADC_VIN: C716.1, R719.1, R724.1, U703.7; also elsewhere on the board
/ref_pll/PHDET_IN: R716.1; also elsewhere on the board
/rf_path/LO_IN: C703.1; also elsewhere on the board
/rf_path/RF_IN: C701.2; also elsewhere on the board
GND: C705.1, C706.2, C707.1, C708.2, C709.1, C710.1, C712.1, C713.1, C714.2, J701.2 (Ext), J702.2 (Ext), J703.2 (Ext), R705.2, R706.1, R714.1, R715.2, R721.1, U701.4 (GND), U701.5 (GND), U701.6 (GND), U702.4 (GND); also elsewhere on the board
unnamed: C701.1, U701.1 (RF)
unnamed: C702.1, U701.2 (LO)
unnamed: C702.2, C703.2, C704.2
unnamed: C704.1, J701.1 (In)
unnamed: C705.2, R720.2, U702.10 (V+)
unnamed: C707.2, R701.1, R721.2, R722.2, U701.3 (IF)
unnamed: C709.2, C710.2, R702.2, U703.8 (V+)
unnamed: C711.1, C715.1, R707.1, R708.2, U703.1
unnamed: C711.2, R703.1, R705.1, R707.2, U703.2 (-)
unnamed: C712.2, R712.1, R713.2
unnamed: C713.2, R710.1, R712.2
unnamed: C714.1, R704.2, R706.2, U703.3 (+)
unnamed: C715.2, R703.2, R704.1, R722.1
unnamed: C716.2, R723.2, U702.1, U702.7, U703.6 (-)
unnamed: J702.1 (In), R701.2
unnamed: J703.1 (In), R709.2
unnamed: R708.1, R709.1, R710.2, R711.2
unnamed: R711.1, U703.5 (+)
unnamed: R713.1, R714.2, R716.2
unnamed: R715.1, R717.2, R723.1
unnamed: R717.1, R718.1, R724.2
unnamed: R718.2, U702.8
unnamed: R719.2, U702.2

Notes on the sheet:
Use absorbptive filter if possible: https://www.markimicrowave.com/blog/dc-offset-and-mixers-as-microwave-phase-detectors/ https://www.analog.com/en/technical-articles/improving-linearity-by-using-absorptive-filters.html
TODO: check noise levels, http://www.wenzel.com/documents/measuringphasenoise.htm
a phase detect calibration path (or, do externally, connect ref to synth output)
3 dB loss
Av = 4
want to be able to measure -160 dBc/Hz signal @ 1 MHz offset assume max convserion loss of 10 dB, 0 dBm input -170 dBc/Hz.. ADC has 100 dB SFDR, 2.5 MSPS (60 dB gain), so DANL of 160 dBFS/Hz full scale is 5Vpp 100 ohms, so 15 dBm DANL of 145 dBm/Hz Need about 25 dB of gain
variable gain amplifier, switch between 10 v/v and 1 v/v from https://www.analog.com/media/en/training-seminars/tutorials/MT-072.pdf
Use ADG621 (start with MAX323 symbol)
Use Sallen-Key low pass filter

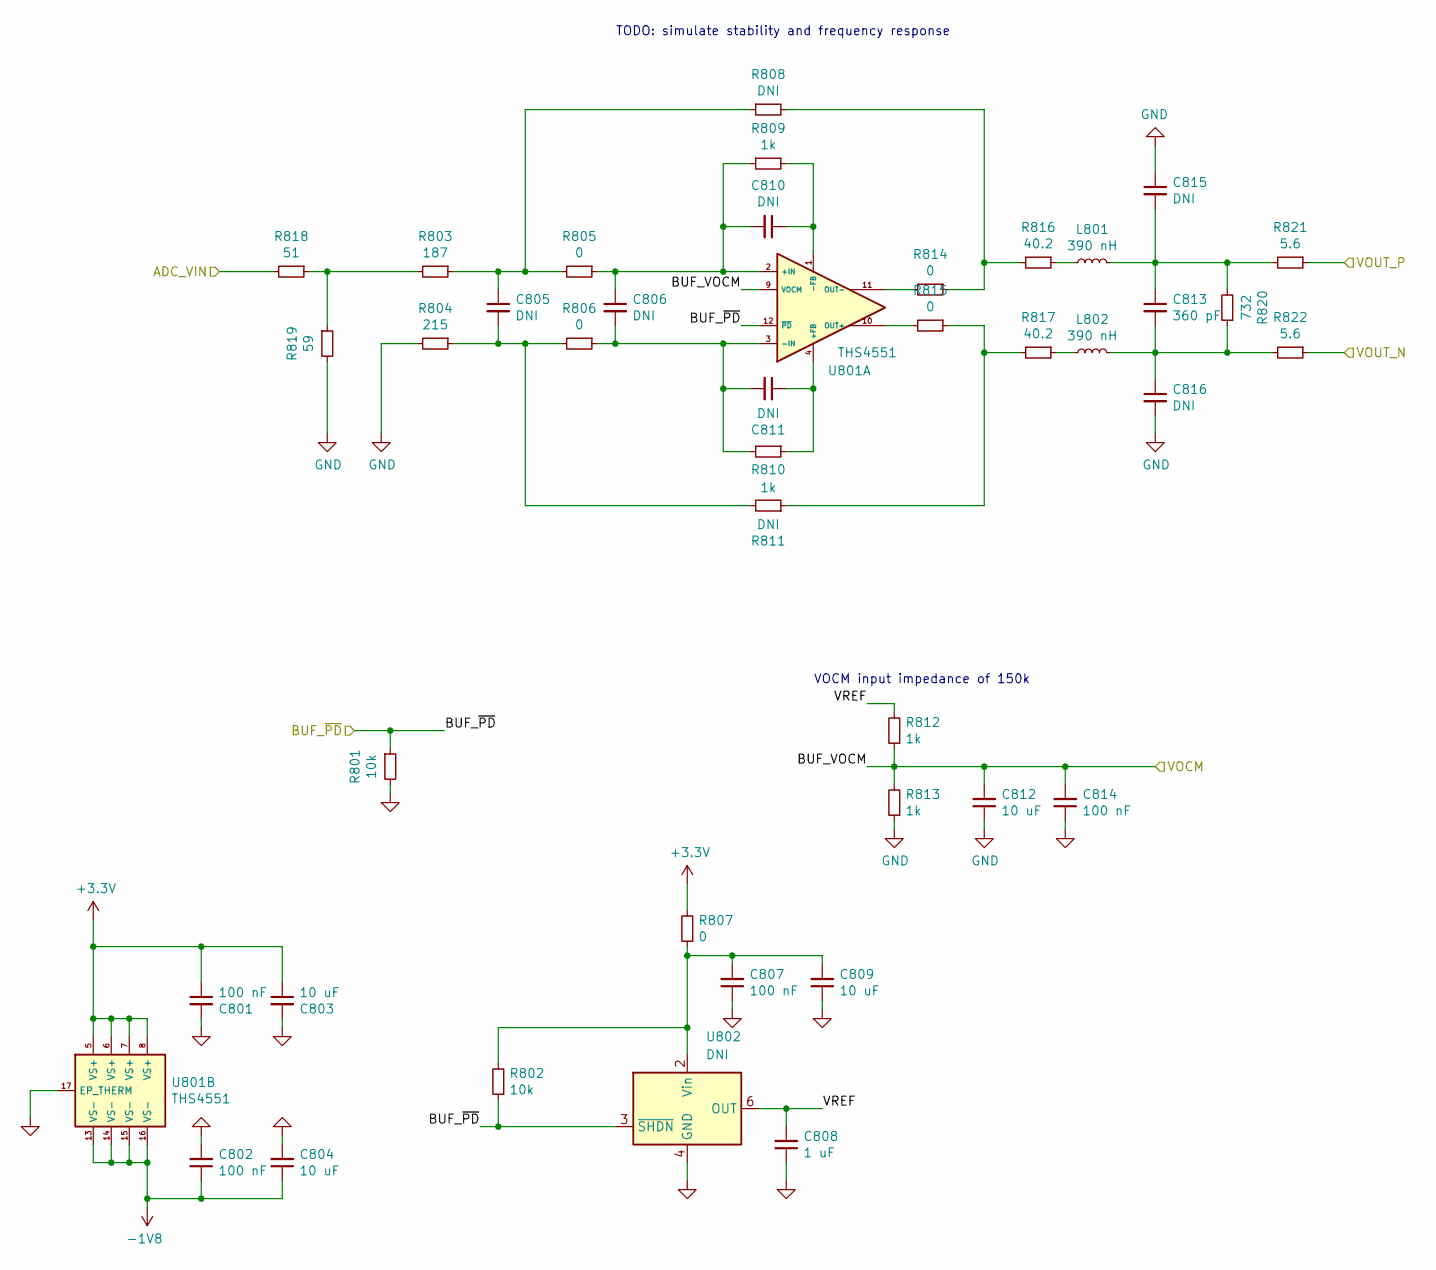
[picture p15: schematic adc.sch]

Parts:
C801, C802, C807, C814: 100 nF; C_0402_1005Metric
C803, C804, C809, C812: 10 uF; C_0603_1608Metric
C805, C810, C811: DNI; C_0603_1608Metric
C806, C815, C816: DNI; C_0402_1005Metric
C808: 1 uF; C_0402_1005Metric
C813: 360 pF; C_0402_1005Metric
L801, L802: 390 nH; L_0603_1608Metric
R801, R802: 10k; R_0402_1005Metric
R803: 187; R_0402_1005Metric
R804: 215; R_0402_1005Metric
R805, R806, R807, R814, R815: 0; R_0402_1005Metric
R808, R811: DNI; R_0402_1005Metric
R809, R810, R812, R813: 1k; R_0402_1005Metric
R816, R817: 40.2; R_0402_1005Metric
R818: 51; R_0402_1005Metric
R819: 59; R_0402_1005Metric
R820: 732; R_0402_1005Metric
R821, R822: 5.6; R_0402_1005Metric
U801: THS4551; VQFN-16-1EP_3x3mm_P0.5mm_EP1.6x1.6mm
U802: DNI; MSOP-8_3x3mm_P0.65mm

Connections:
-1V8: C802.1, C804.1, U801.13 (VS-), U801.14 (VS-), U801.15 (VS-), U801.16 (VS-); also elsewhere on the board
/BUF_~PD: R801.1, R802.1, U801.12 (~PD), U802.3 (~SHDN); also elsewhere on the board
/adc/ADC_VIN: R818.2; also elsewhere on the board
/adc/VOCM: C812.2, C814.2, R812.1, R813.2, U801.9 (VOCM); also elsewhere on the board
/adc/VOUT_N: R822.1; also elsewhere on the board
/adc/VOUT_P: R821.1; also elsewhere on the board
/adc/VREF: C808.2, R812.2, U802.6 (OUT)
GND: C801.2, C802.2, C803.2, C804.2, C807.1, C808.1, C809.1, C812.1, C814.1, C815.1, C816.2, R801.2, R804.2, R813.1, R819.2, U801.17 (EP_THERM), U802.4 (GND); also elsewhere on the board
unnamed: C805.1, R803.1, R805.2, R808.1
unnamed: C805.2, R804.1, R806.2, R811.2
unnamed: C806.1, C810.2, R805.1, R809.1, U801.2 (+IN)
unnamed: C806.2, C811.2, R806.1, R810.2, U801.3 (-IN)
unnamed: C807.2, C809.2, R802.2, R807.1, U802.2 (Vin)
unnamed: C810.1, R809.2, U801.1 (-FB)
unnamed: C811.1, R810.1, U801.4 (+FB)
unnamed: C813.1, C815.2, L801.2, R820.2, R821.2
unnamed: C813.2, C816.1, L802.2, R820.1, R822.2
unnamed: L801.1, R816.1
unnamed: L802.1, R817.1
unnamed: R803.2, R818.1, R819.1
unnamed: R808.2, R814.1, R816.2
unnamed: R811.1, R815.1, R817.2
unnamed: R814.2, U801.11 (OUT-)
unnamed: R815.2, U801.10 (OUT+)

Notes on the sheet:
VOCM input impedance of 150k
TODO: simulate stability and frequency response

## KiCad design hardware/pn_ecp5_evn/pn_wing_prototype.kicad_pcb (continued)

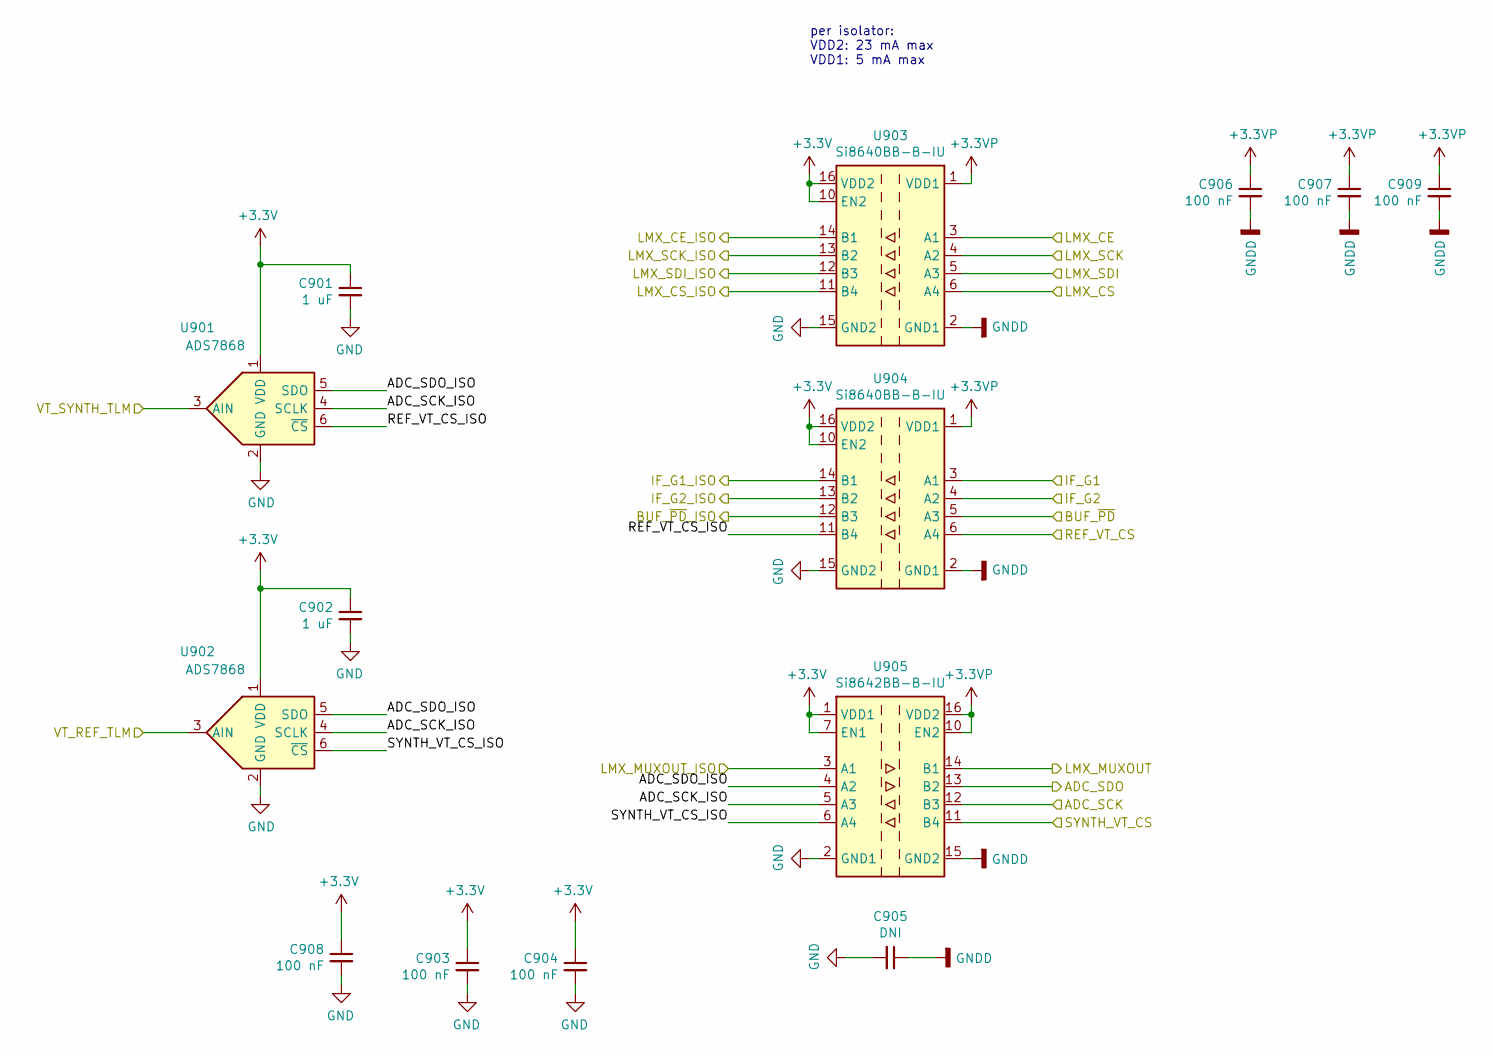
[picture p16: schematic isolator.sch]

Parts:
C901, C902: 1 uF; C_0402_1005Metric
C903, C904, C906, C907, C908, C909: 100 nF; C_0402_1005Metric
C905: DNI; C_0402_1005Metric
U901, U902: ADS7868; TSOT-23-6
U903, U904: Si8640BB-B-IU; QSOP-16_3.9x4.9mm_P0.635mm
U905: Si8642BB-B-IU; QSOP-16_3.9x4.9mm_P0.635mm

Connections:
+3.3VP: C906.1, C907.1, C909.1, U903.1 (VDD1), U904.1 (VDD1), U905.10 (EN2), U905.16 (VDD2); also elsewhere on the board
/BUF_~PD: U904.12 (B3); also elsewhere on the board
/IF_G1: U904.14 (B1); also elsewhere on the board
/IF_G2: U904.13 (B2); also elsewhere on the board
/LMX_CE: U903.14 (B1); also elsewhere on the board
/LMX_CSB: U903.11 (B4); also elsewhere on the board
/LMX_MUXout: U905.3 (A1); also elsewhere on the board
/LMX_SCK: U903.13 (B2); also elsewhere on the board
/LMX_SDI: U903.12 (B3); also elsewhere on the board
/VT_REF_TLM: U902.3 (AIN); also elsewhere on the board
/VT_SYNTH_TLM: U901.3 (AIN); also elsewhere on the board
/isolator/ADC_SCK: U905.12 (B3); also elsewhere on the board
/isolator/ADC_SCK_ISO: U901.4 (SCLK), U902.4 (SCLK), U905.5 (A3)
/isolator/ADC_SDO: U905.13 (B2); also elsewhere on the board
/isolator/ADC_SDO_ISO: U901.5 (SDO), U902.5 (SDO), U905.4 (A2)
/isolator/BUF_~PD: U904.5 (A3); also elsewhere on the board
/isolator/IF_G1: U904.3 (A1); also elsewhere on the board
/isolator/IF_G2: U904.4 (A2); also elsewhere on the board
/isolator/LMX_CE: U903.3 (A1); also elsewhere on the board
/isolator/LMX_CS: U903.6 (A4); also elsewhere on the board
/isolator/LMX_MUXOUT: U905.14 (B1); also elsewhere on the board
/isolator/LMX_SCK: U903.4 (A2); also elsewhere on the board
/isolator/LMX_SDI: U903.5 (A3); also elsewhere on the board
/isolator/REF_VT_CS: U904.6 (A4); also elsewhere on the board
/isolator/REF_VT_CS_ISO: U901.6 (~CS), U904.11 (B4)
/isolator/SYNTH_VT_CS: U905.11 (B4); also elsewhere on the board
/isolator/SYNTH_VT_CS_ISO: U902.6 (~CS), U905.6 (A4)
GND: C901.2, C902.2, C903.2, C904.2, C905.2, C908.2, U901.2 (GND), U902.2 (GND), U903.9 (GND2), U903.15 (GND2), U904.9 (GND2), U904.15 (GND2), U905.2 (GND1), U905.8 (GND1); also elsewhere on the board
GNDD: C905.1, C906.2, C907.2, C909.2, U903.2 (GND1), U903.8 (GND1), U904.2 (GND1), U904.8 (GND1), U905.9 (GND2), U905.15 (GND2); also elsewhere on the board

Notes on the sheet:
per isolator: VDD2: 23 mA max VDD1: 5 mA max

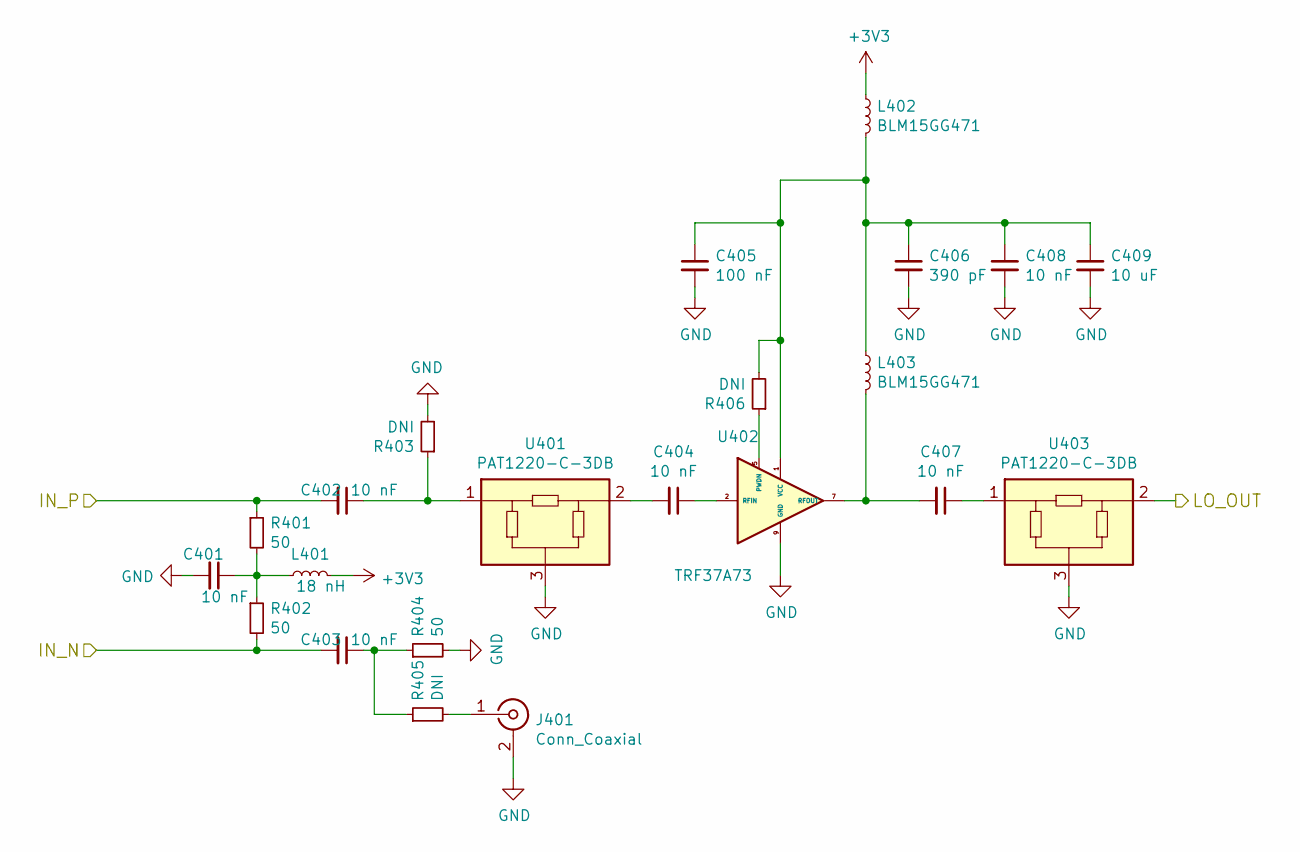
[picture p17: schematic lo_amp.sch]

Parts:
C301, C302, C303, C304, C307, C308: 10 nF; C_0402_1005Metric
C305: 100 nF; C_0402_1005Metric
C306: 390 pF; C_0603_1608Metric
C309: 10 uF; C_0603_1608Metric
J401: Conn_Coaxial; U.FL_Hirose_U.FL-R-SMT-1_Vertical
L301: 18 nH; L_0402_1005Metric
L302, L303: BLM15GG471; L_0402_1005Metric
R301, R302, R304: 50; R_0402_1005Metric
R303, R305, R306: DNI; R_0402_1005Metric
U301, U303: PAT1220-C-3DB; RF_Attenuator_Susumu_PAT1220
U302: TRF37A73; WSON-8-1EP_2x2mm_P0.5mm_EP0.9x1.6mm

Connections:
/rf_path/LO_IN: U303.2; also elsewhere on the board
/synth/lo_amp/IN_N: C303.2, R302.2; also elsewhere on the board
/synth/lo_amp/IN_P: C302.2, R301.1; also elsewhere on the board
GND: C301.2, C305.2, C306.2, C308.2, C309.2, J401.2 (Ext), R303.2, R304.2, U301.3, U302.9 (GND), U303.3; also elsewhere on the board
unnamed: C301.1, L301.1, R301.2, R302.1
unnamed: C302.1, R303.1, U301.1
unnamed: C303.1, R304.1, R305.1
unnamed: C304.1, U302.2 (RFIN)
unnamed: C304.2, U301.2
unnamed: C305.1, C306.1, C308.1, C309.1, L302.2, L303.1, R306.2, U302.1 (VCC)
unnamed: C307.1, U303.1
unnamed: C307.2, L303.2, U302.7 (RFOUT)
unnamed: R306.1, U302.5 (PWDN)

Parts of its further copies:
C401, C402, C403, C404, C407, C408: 10 nF; C_0402_1005Metric
C405: 100 nF; C_0402_1005Metric
C406: 390 pF; C_0603_1608Metric
C409: 10 uF; C_0603_1608Metric
J301: Conn_Coaxial; U.FL_Hirose_U.FL-R-SMT-1_Vertical
L401: 18 nH; L_0402_1005Metric
L402, L403: BLM15GG471; L_0402_1005Metric
R401, R402, R404: 50; R_0402_1005Metric
R403, R405, R406: DNI; R_0402_1005Metric
U401, U403: PAT1220-C-3DB; RF_Attenuator_Susumu_PAT1220
U402: TRF37A73; WSON-8-1EP_2x2mm_P0.5mm_EP0.9x1.6mm

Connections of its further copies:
/synth/aux_output/IN_N: C403.2, R402.2; also elsewhere on the board
/synth/aux_output/IN_P: C402.2, R401.1; also elsewhere on the board
/synth/aux_output/LO_OUT: U403.2; also elsewhere on the board
GND: C401.2, C405.2, C406.2, C408.2, C409.2, J301.2 (Ext), R403.2, R404.2, U401.3, U402.9 (GND), U403.3; also elsewhere on the board
unnamed: C401.1, L401.1, R401.2, R402.1
unnamed: C402.1, R403.1, U401.1
unnamed: C403.1, R404.1, R405.1
unnamed: C404.1, U402.2 (RFIN)
unnamed: C404.2, U401.2
unnamed: C405.1, C406.1, C408.1, C409.1, L402.2, L403.1, R406.2, U402.1 (VCC)
unnamed: C407.1, U403.1
unnamed: C407.2, L403.2, U402.7 (RFOUT)
unnamed: R406.1, U402.5 (PWDN)

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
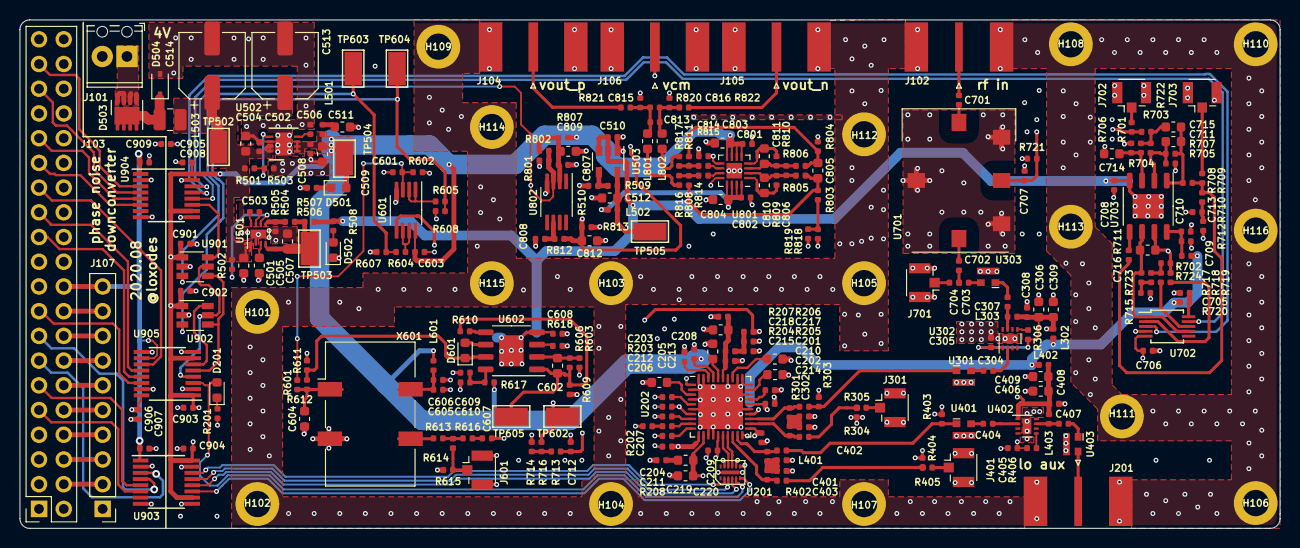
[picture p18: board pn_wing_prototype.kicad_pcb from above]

Board: 4 copper layers, 129.5 x 52.2 mm, 277 parts (0 on the bottom side), 167 nets.

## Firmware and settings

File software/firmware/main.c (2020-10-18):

#include <stdio.h>
#include <stdlib.h>
#include <string.h>

#include <irq.h>
#include <uart.h>
#include <time.h>
#include <console.h>
#include <generated/csr.h>
#include <generated/mem.h>

#define NO_READBACK 0
#define READBACK 1



static char *readstr(void)
{
	char c[2];
	static char s[64];
	static int ptr = 0;

	if(readchar_nonblock()) {
		c[0] = readchar();
		c[1] = 0;
		switch(c[0]) {
			case 0x7f:
			case 0x08:
				if(ptr > 0) {
					ptr--;
					putsnonl("\x08 \x08");
				}
				break;
			case 0x07:
				break;
			case '\r':
			case '\n':
				s[ptr] = 0x00;
				putsnonl("\n");
				ptr = 0;
				return s;
			default:
				if(ptr >= (sizeof(s) - 1))
					break;
				putsnonl(c);
				s[ptr] = c[0];
				ptr++;
				break;
		}
	}

	return NULL;
}

static char *get_token(char **str)
{
	char *c, *d;

	c = (char *)strchr(*str, ' ');
	if(c == NULL) {
		d = *str;
		*str = *str+strlen(*str);
		return d;
	}
	*c = 0;
	d = *str;
	*str = c+1;
	return d;
}

static void prompt(void)
{
	printf("RUNTIME>");
}

static void help(void)
{
	puts("Available commands:");
	puts("help                            - this command");
	puts("reboot                          - reboot CPU");
	puts("memory                          - memory test");
	puts("wishbone                        - wishbone dma test");
	puts("adc                        	 - adc test");
	puts("synth                           - synth test");
}

static void reboot(void)
{
  	ctrl_reset_write(1);
}

static uint32_t adc_spi_read(uint16_t addr)
{
	while(adc_spi_status_read() != 1 << CSR_ADC_SPI_STATUS_DONE_OFFSET) {
		;
	}

	uint32_t spi_control_start = (24 << CSR_ADC_SPI_CONTROL_LENGTH_OFFSET) | (1 << CSR_ADC_SPI_CONTROL_START_OFFSET);
	adc_spi_cs_write(1);
	adc_spi_mosi_write((addr << 8) + (1 << 23) + (1 << 22));
	adc_spi_control_write(spi_control_start);

	while(adc_spi_status_read() != 1 << CSR_ADC_SPI_STATUS_DONE_OFFSET) {
		;
	}

	adc_spi_cs_write(0);
	uint32_t r = adc_spi_miso_read();
	return r & 0xFF;

}


static uint8_t adc_spi_write(uint16_t addr, uint8_t value)
{
	while(adc_spi_status_read() != 1 << CSR_ADC_SPI_STATUS_DONE_OFFSET) {
		;
	}

	uint32_t spi_control_start = (24 << CSR_ADC_SPI_CONTROL_LENGTH_OFFSET) | (1 << CSR_ADC_SPI_CONTROL_START_OFFSET);


	uint32_t payload = (1 << 22) + (addr << 8) + value;
	adc_spi_cs_write(1);
	adc_spi_mosi_write(payload);
	adc_spi_control_write(spi_control_start);

	while(adc_spi_status_read() != 1 << CSR_ADC_SPI_STATUS_DONE_OFFSET) {
		;
	}

	adc_spi_cs_write(0);

	uint8_t r = adc_spi_read(addr);

	if(r != value) {
		printf("adc readback after write to %x failed!, expected %x got %x\n", addr, value, r);
	}
	return r;
}

static uint16_t synth_spi_read(uint8_t addr)
{
	while(synth_spi_status_read() != 1 << CSR_SYNTH_SPI_STATUS_DONE_OFFSET) {
		;
	}
	uint32_t spi_control_start = (24 << CSR_SYNTH_SPI_CONTROL_LENGTH_OFFSET) | (1 << CSR_SYNTH_SPI_CONTROL_START_OFFSET);
	uint32_t payload = (1 << 23) + (addr << 16);

	synth_spi_cs_write(1);
	synth_spi_mosi_write(payload);
	synth_spi_control_write(spi_control_start);

	while(synth_spi_status_read() != 1 << CSR_SYNTH_SPI_STATUS_DONE_OFFSET) {
		;
	}

	synth_spi_cs_write(0);
	uint32_t r = synth_spi_miso_read() & 0xFFFF;
	return r;
}

static uint16_t synth_spi_write(uint16_t addr, uint16_t value, uint8_t readback)
{
	// https://github.com/loxodes/vna/blob/devel/software/vna_controller/bbone_spi_bitbang.py
	while(synth_spi_status_read() != 1 << CSR_SYNTH_SPI_STATUS_DONE_OFFSET) {
		;
	}

	uint32_t spi_control_start = (24 << CSR_SYNTH_SPI_CONTROL_LENGTH_OFFSET) | (1 << CSR_SYNTH_SPI_CONTROL_START_OFFSET);
	uint32_t payload = (0 << 23) + (addr << 16) + value;
	uint16_t r = 0;

	synth_spi_cs_write(1);
	synth_spi_mosi_write(payload);
	synth_spi_control_write(spi_control_start);
	while(synth_spi_status_read() != 1 << CSR_SYNTH_SPI_STATUS_DONE_OFFSET) {
		;
	}
	synth_spi_cs_write(0);

	if(readback) {
		r = synth_spi_read(addr);

		if(r != value) {
			printf("synth readback after write to %x failed!, expected %x got %x\n", addr, value, r);
		}
	}

	return r;
}



static void adc_init(void)
{
	// setup for 2-Wire (6x serialization)
	// Fs = 25 MSPS, Fbit = 150 MHz
	
	// soft reset
	adc_spi_write(0x06, 0x01);
	adc_spi_write(0x06, 0x00);
	// high pulse on reset, minimum duration 10 nanoseconds
	// max SPI SCLK 20 MHz
	// 0x01, default ok, dithering on both channels
	// 0x03, default ok, bits 0,1,2 on wire 0, bits 7,8,9 on wire 1
	// 0x04, default ok, do not flip output wires
	// 0x05, default ok, transmit on two output wires
	// 0x06, default ok, normal output (not a test pattern)
	// 0x07, default ok, bit 0 is lsb
	adc_spi_write(0x09, 0x01); // 0x09, set data format as offset binary
	// 0x0a, default ok, normal operation (not a test pattern)
	// 0x0b, default ok, normal operation (not a test pattern)
	// 0x0e, default ok
	// 0x0f, default ok
	// 0x13, default ok, >25 MSPS
	// 0x15, default ok, enable both channels and normal operation
	// 0x25, default ok, max LVDS swing
	// 0x27, default ok, no sample clock division
	// 0x41D, default ok, <100 MHz operation
	// 0x422, default ok, chopper enabled on ch a
	// 0x434, default ok, dithering on cha
	adc_spi_write(0x439, 0x08);
	// 0x439, write 0b1000 after reset for best performance on ch a
	// 0x51D, default ok, <100 MHz operation
	// 0x522, default ok, chopper enabled on ch b
	// 0x534, default ok, dithering on channel a
	adc_spi_write(0x539, 0x08);
	// 0x539, write 0b1000 after reset for best performance on ch b
	// 0x608, default ok, <100 MHz operation

	adc_spi_write(0x70A, 0x01);
	// 0x70A, 0b1, disable sysref buffer
}


static void adc_testpattern_en(void)
{
	adc_spi_write(0x06, 0x02);
	adc_spi_write(0x0a, 0x04);
	adc_spi_write(0x0b, 0x09<<4);


	// custom pattern:
	adc_spi_write(0x0e, 0x16);
	adc_spi_write(0x0f, 0x50); // 0x05

	// 0a
	// 0 - normal
	// 1 - all 0
	// 2 - all 1
	// 3 - alternate 010101 101010 
	// 4 - ramp, datasheet is incorrect, value increments every 4 samples (https://e2e.ti.com/support/data-converters/f/73/t/469423)
	// 5 - custom pattern
	// 9 - 8 point sine wave, [0, 599,2048,3496,4095,3496,2048,599]
	// 10 - Deskew pattern, data are AAAh
}

static void adc_testpattern_disable(void)
{
	adc_spi_write(0x06, 0x00);
	adc_spi_write(0x0a, 0x00);
	adc_spi_write(0x0b, 0x00);
}

static void adc_test(void)
{
	// capture a burst, 20 MSPS, a
	// provide a 20 MHz sample clock
	// read in data at .. 120 MHz
	//
	uint16_t burst_size = 10;
	volatile uint32_t *dram_array = (uint32_t *)(HYPERRAM_BASE);
	adc_init();
	adc_testpattern_disable();

	adc_burst_size_write(burst_size);
	adc_base_write(HYPERRAM_BASE);
	adc_offset_write(0);

	adc_start_write(1 << CSR_ADC_START_START_BURST_OFFSET);

	printf("waiting for ready!\n");

	// flush cache before accessing shared memory..
	flush_cpu_icache();
	flush_cpu_dcache();

	while(!adc_ready_read())
	{
		;
	}

	printf("memory readback!\n");
	for(uint16_t i=0; i<burst_size; i++) {
		printf("memory[%d]: %d\n", i, dram_array[i]);
	}


}


static void memory_test(void)
{
	// offset data in RAM from the start to avoid overwriting firmware..
	volatile uint32_t *dram_array = (unsigned int *)(HYPERRAM_BASE);

	int i;
	printf("memory test...\n");
	
	printf("writing memory to base %x!\n", dram_array);
	printf("HYPERRAM_BASE is %x!\n", HYPERRAM_BASE);
	for(i=0; i<500000; i++) {
		//#printf("writing memory, %d!\n", i);
		dram_array[i] = 0;
	}
	
	printf("memory readback!\n");
	for(i=0; i<1024; i++) {
		// 	printf("reading memory[%d] = %d\n", i, dram_array[i]);
		if(dram_array[i] == 0) {
			;
		}
		else {
			printf("pattern mismatch!, read %d expected %d\n", dram_array[i], i*4);
		}

	}
	printf("test complete!\n");
	
}

static void synth_test(void)
{
	// hardcoded for 500 MHz output on channel B
	printf("resetting LMX2594...\n");
	// program RESET=1 to reset registers
	synth_spi_write(0, 2, NO_READBACK);

	// program RESET=0 to remove reset, set MUXOUT to readback
	synth_spi_write(0, 0x2518, READBACK);

	printf("programming LMX2594...\n");
	// program register values in reverse order, from lowest to highest
	synth_spi_write(112,0x0000,READBACK);
	synth_spi_write(111,0x0000,READBACK);
	synth_spi_write(110,0x0000,READBACK);
	synth_spi_write(109,0x0000,READBACK);
	synth_spi_write(108,0x0000,READBACK);
	synth_spi_write(107,0x0000,READBACK);
	synth_spi_write(106,0x0000,READBACK);
	synth_spi_write(105,0x0021,READBACK);
	synth_spi_write(104,0x0000,READBACK);
	synth_spi_write(103,0x0000,READBACK);
	synth_spi_write(102,0x0000,READBACK);
	synth_spi_write(101,0x0011,READBACK);
	synth_spi_write(100,0x0000,READBACK);
	synth_spi_write(99,0x0000,READBACK);
	synth_spi_write(98,0x0000,READBACK);
	synth_spi_write(97,0x0888,READBACK);
	synth_spi_write(96,0x0000,READBACK);
	synth_spi_write(95,0x0000,READBACK);
	synth_spi_write(94,0x0000,READBACK);
	synth_spi_write(93,0x0000,READBACK);
	synth_spi_write(92,0x0000,READBACK);
	synth_spi_write(91,0x0000,READBACK);
	synth_spi_write(90,0x0000,READBACK);
	synth_spi_write(89,0x0000,READBACK);
	synth_spi_write(88,0x0000,READBACK);
	synth_spi_write(87,0x0000,READBACK);
	synth_spi_write(86,0x0000,READBACK);
	synth_spi_write(85,0x0000,READBACK);
	synth_spi_write(84,0x0000,READBACK);
	synth_spi_write(83,0x0000,READBACK);
	synth_spi_write(82,0x0000,READBACK);
	synth_spi_write(81,0x0000,READBACK);
	synth_spi_write(80,0x0000,READBACK);
	synth_spi_write(79,0x0000,READBACK);
	synth_spi_write(78,0x0003,READBACK);
	synth_spi_write(77,0x0000,READBACK);
	synth_spi_write(76,0x000C,READBACK);
	synth_spi_write(75,0x0AC0,READBACK);
	synth_spi_write(74,0x0000,READBACK);
	synth_spi_write(73,0x003F,READBACK);
	synth_spi_write(72,0x0001,READBACK);
	synth_spi_write(71,0x0081,READBACK);
	synth_spi_write(70,0xC350,READBACK);
	synth_spi_write(69,0x0000,READBACK);
	synth_spi_write(68,0x03E8,READBACK);
	synth_spi_write(67,0x0000,READBACK);
	synth_spi_write(66,0x01F4,READBACK);
	synth_spi_write(65,0x0000,READBACK);
	synth_spi_write(64,0x1388,READBACK);
	synth_spi_write(63,0x0000,READBACK);
	synth_spi_write(62,0x0322,READBACK);
	synth_spi_write(61,0x00A8,READBACK);
	synth_spi_write(60,0x0000,READBACK);
	synth_spi_write(59,0x0001,READBACK);
	synth_spi_write(58,0x9001,READBACK);
	synth_spi_write(57,0x0020,READBACK);
	synth_spi_write(56,0x0000,READBACK);
	synth_spi_write(55,0x0000,READBACK);
	synth_spi_write(54,0x0000,READBACK);
	synth_spi_write(53,0x0000,READBACK);
	synth_spi_write(52,0x0820,READBACK);
	synth_spi_write(51,0x0080,READBACK);
	synth_spi_write(50,0x0000,READBACK);
	synth_spi_write(49,0x4180,READBACK);
	synth_spi_write(48,0x0300,READBACK);
	synth_spi_write(47,0x0300,READBACK);
	synth_spi_write(46,0x07FC,READBACK);
	synth_spi_write(45,0xC0DF,READBACK);
	synth_spi_write(44,0x01A3,READBACK);
	synth_spi_write(43,0x0000,READBACK);
	synth_spi_write(42,0x0000,READBACK);
	synth_spi_write(41,0x0000,READBACK);
	synth_spi_write(40,0x0000,READBACK);
	synth_spi_write(39,0x03E8,READBACK);
	synth_spi_write(38,0x0000,READBACK);
	synth_spi_write(37,0x0304,READBACK);
	synth_spi_write(36,0x0030,READBACK);
	synth_spi_write(35,0x0004,READBACK);
	synth_spi_write(34,0x0000,READBACK);
	synth_spi_write(33,0x1E21,READBACK);
	synth_spi_write(32,0x0393,READBACK);
	synth_spi_write(31,0x43EC,READBACK);
	synth_spi_write(30,0x318C,READBACK);
	synth_spi_write(29,0x318C,READBACK);
	synth_spi_write(28,0x0488,READBACK);
	synth_spi_write(27,0x0002,READBACK);
	synth_spi_write(26,0x0DB0,READBACK);
	synth_spi_write(25,0x0C2B,READBACK);
	synth_spi_write(24,0x071A,READBACK);
	synth_spi_write(23,0x007C,READBACK);
	synth_spi_write(22,0x0001,READBACK);
	synth_spi_write(21,0x0401,READBACK);
	synth_spi_write(20,0xE048,READBACK);
	synth_spi_write(19,0x27B7,READBACK);
	synth_spi_write(18,0x0064,READBACK);
	synth_spi_write(17,0x012C,READBACK);
	synth_spi_write(16,0x0080,READBACK);
	synth_spi_write(15,0x064F,READBACK);
	synth_spi_write(14,0x1E70,READBACK);
	synth_spi_write(13,0x4000,READBACK);
	synth_spi_write(12,0x5001,READBACK);
	synth_spi_write(11,0x0018,READBACK);
	synth_spi_write(10,0x10D8,READBACK);
	synth_spi_write(9,0x1604,READBACK);
	synth_spi_write(8,0x2000,READBACK);
	synth_spi_write(7,0x40B2,READBACK);
	synth_spi_write(6,0xC802,READBACK);
	synth_spi_write(5,0x00C8,READBACK);
	synth_spi_write(4,0x0A43,READBACK);
	synth_spi_write(3,0x0642,READBACK);
	synth_spi_write(2,0x0500,READBACK);
	synth_spi_write(1,0x0808,READBACK);
	synth_spi_write(0,0x251C,READBACK);
	// wait 10 ms
	printf("initialization complete, waiting for final FCAL_EN...\n");
	busy_wait(1000);

	// program register 0 one more time with FCAL_EN = 1
	// set MUXOUT to lock detect
	synth_spi_write(0, 0x251C, NO_READBACK);
	printf("programming complete\n");
}

static void console_service(void)
{
	char *str;
	char *token;

	str = readstr();
	if(str == NULL) return;
	token = get_token(&str);
	if(strcmp(token, "help") == 0)
		help();
	else if(strcmp(token, "reboot") == 0)
		reboot();
	else if(strcmp(token, "memory") == 0)
		memory_test();
	else if(strcmp(token, "adc") == 0)
		adc_test();
	else if(strcmp(token, "synth") == 0)
		synth_test();
	prompt();
}


static void pn_init(void)
{
	// enable 
	// bit
	// 0	if_g1
	// 1	if_g2
	// 2	buf_pd
	// 3 	synth_ce
	pn_gpio_out_write(0x08);//8 for synth_ce only
}


int main(void)
{
	irq_setmask(0);
	irq_setie(1);
	uart_init();
	pn_init();

	puts("\nCPU testing software built "__DATE__" "__TIME__"\n");
	help();
	prompt();

	while(1) {
		console_service();
	}

	return 0;
}

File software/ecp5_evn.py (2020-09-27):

#!/usr/bin/env python3

# This file is Copyright (c) 2019 Arnaud Durand <arnaud.durand@unifr.ch>
# License: BSD

import os
import argparse

from migen import *
from migen.genlib.resetsync import AsyncResetSynchronizer

from litex_boards.platforms import ecp5_evn
from litex.build.generic_platform import Subsignal, Pins, IOStandard
from litex.build.tools import write_to_file

from litex.soc.cores.clock import *
from litex.soc.integration.soc_core import *
from litex.soc.integration.builder import *
from litex.soc.integration import export

from litex.soc.cores.spi import SPIMaster
from litex.soc.cores.gpio import GPIOOut
from litex.soc.cores.led import LedChaser
from litex.soc.cores.uart import UARTWishboneBridge
#from litehyperbus.core.hyperram_ddrx2 import HyperRAMX2
from litehyperbus.core.hyperbus import HyperRAM

from litescope import LiteScopeAnalyzer

from ddr_test import ADC3321_DMA

# CRG ----------------------------------------------------------------------------------------------

class _CRG(Module):
    def __init__(self, platform, sys_clk_freq, x5_clk_freq):
        self.clock_domains.cd_sys = ClockDomain()
        self.clock_domains.cd_adc_bitclk = ClockDomain()
        self.clock_domains.cd_adc_sampleclk = ClockDomain()
        # # # 
        adc_clks = platform.request("adc_clks")

        # clk / rst
        clk = clk12 = platform.request("clk12")
        rst_n = platform.request("rst_n")
        if x5_clk_freq is not None:
            clk = clk50 = platform.request("ext_clk50")
            self.comb += platform.request("ext_clk50_en").eq(1)
            platform.add_period_constraint(clk50, 1e9/x5_clk_freq)


        # sysclk pll, also generate sample clock
        sampleclk_freq = 25e6
        self.submodules.pll = pll = ECP5PLL()
        self.comb += pll.reset.eq(~rst_n)
        pll.register_clkin(clk, x5_clk_freq or 12e6)
        pll.create_clkout(self.cd_sys, sys_clk_freq)
        pll.create_clkout(self.cd_adc_sampleclk, sampleclk_freq)
        self.comb += adc_clks.sclk.eq(~self.cd_adc_sampleclk.clk)
        self.specials += AsyncResetSynchronizer(self.cd_sys, ~rst_n)

        # bitclk pll
        bitclk_freq = 150e6
        self.submodules.bitclk_pll = bitclk_pll = ECP5PLL()
        platform.add_period_constraint(adc_clks.dclk, 1e9/bitclk_freq)

        self.comb += bitclk_pll.reset.eq(~rst_n)
        bitclk_pll.register_clkin(adc_clks.dclk, bitclk_freq)
        bitclk_pll.create_clkout(self.cd_adc_bitclk, bitclk_freq, phase = 200)#200)


# BaseSoC ------------------------------------------------------------------------------------------
class BaseSoC(SoCCore):
    mem_map = {
        "hyperram" : 0x20000000,
        "adc_sram" : 0x30000000,
    }
    mem_map.update(SoCCore.mem_map)

    def _add_extentions(self, platform):
        platform.add_extension([
            ("serial_wb", 1,
                Subsignal("rx", Pins("E9")),
                Subsignal("tx", Pins("D9")),
                IOStandard("LVCMOS33")
            ),

            ("debug_pins", 1,
                Subsignal("dbg1", Pins("B6")),
                Subsignal("dbg2", Pins("C9")),
                Subsignal("dbg3", Pins("D10")),
                IOStandard("LVCMOS33")
            ),

            ("adc_data", 0,
                Subsignal("da0", Pins("A4")), # INVERTED
                Subsignal("da1", Pins("B5")), # INVERTED
                Subsignal("db0", Pins("E4")), # INVERTED
                Subsignal("db1", Pins("C3")), # INVERTED
                Subsignal("fclk", Pins("A3")), # INVERTED
                Subsignal("sysref", Pins("E5")), # INVERTED
                IOStandard("LVDS")
            ),

            ("adc_spi", 1,
                Subsignal("clk",   Pins("C6")),
                Subsignal("mosi", Pins("C7")),
                Subsignal("cs_n",    Pins("E8")),
                Subsignal("miso",  Pins("D8")),
                IOStandard("LVCMOS33")
            ),

            ("adc_ctrl", 0,
                Subsignal("en_pwr",  Pins("A7")),
                Subsignal("pdn",  Pins("C8")),
                Subsignal("reset",  Pins("B8")),
                IOStandard("LVCMOS33")
            ),

            ("adc_clks", 0,
                Subsignal("dclk", Pins("C4")), # INVERTED...
                Subsignal("sclk", Pins("F4")), # INVERTED
                IOStandard("LVDS")
            ),

            ("hyperram", 0,
                Subsignal("clk",   Pins("B13")),
                Subsignal("rst_n", Pins("C15")),
                Subsignal("dq",    Pins("D11 C12 E11 B12 E12 C13 D13 D12")),
                Subsignal("cs_n",  Pins("B15")),
                Subsignal("rwds",  Pins("B20")),
                IOStandard("LVCMOS33")
            ),

            ("vt_adc_spi", 0,
                Subsignal("clk",   Pins("N4")),
                Subsignal("miso",  Pins("E14")),
                Subsignal("mosi",  Pins("N3")),
                Subsignal("cs_synth",  Pins("M4")),
                Subsignal("cs_ref",  Pins("L4")),
                IOStandard("LVCMOS33")
            ),

            ("synth_spi", 0,
                Subsignal("clk",  Pins("L3")),
                Subsignal("mosi",  Pins("L2")),
                Subsignal("cs_n",  Pins("L1")),
                Subsignal("miso",  Pins("M5")),
                IOStandard("LVCMOS33")
            ),

            ("pn_control", 0,
                Subsignal("if_g1",  Pins("A15")),
                Subsignal("if_g2",  Pins("H2")),
                Subsignal("buf_pd", Pins("J3")),
                Subsignal("synth_ce", Pins("N2")),
                IOStandard("LVCMOS33")
            ),
        ])

    def __init__(self, sys_clk_freq=int(50e6), x5_clk_freq=None, toolchain="trellis", **kwargs):
        from litex.build.generic_platform import Subsignal, Pins, IOStandard
        platform = ecp5_evn.Platform(toolchain=toolchain)
        self._add_extentions(platform)

        # SoCCore ----------------------------------------------------------------------------------
        SoCCore.__init__(self, platform, clk_freq=sys_clk_freq, integrated_main_ram_size=0x8000, **kwargs)

        # CRG --------------------------------------------------------------------------------------
        crg = _CRG(platform, sys_clk_freq, x5_clk_freq)
        self.submodules.crg = crg

        # HyperRam ---------------------------------------------------------------------------------
        self.submodules.hyperram = HyperRAM(platform.request("hyperram"))
        #self.submodules.hyperram = HyperRAMX2(platform.request("hyperram"))

        self.add_wb_slave(self.mem_map["hyperram"], self.hyperram.bus)
        self.add_memory_region("hyperram", self.mem_map["hyperram"], 8*1024*1024)

        # ADC RAM
        self.add_ram("adc_sram", self.mem_map["adc_sram"], 8*4*4096)

        # ADC --------------------------------------------------------------------------------------
        adc_ctrl = platform.request("adc_ctrl", 0)
        adc_data = platform.request("adc_data", 0)
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

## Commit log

2020-08-10 added initial schematic of phase noise analyzer - in progress
    [adc.sch, isolator.sch, lo_amp.sch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]
2020-08-10 first pass footprint assignment on pn r0
    [adc.sch, isolator.sch, lo_amp.sch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]
2020-08-17 started component placement on phase noise analyzer
    [adc.sch, isolator.sch, pn_wing_prototype.kicad_pcb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]
2020-08-23 component placement on phase noise downconverter
    [pn_wing_prototype.kicad_pcb, pn_wing_prototype.sch, synth.sch]
2020-08-23 first pass component placement on phase noise downconverter
    [pn_wing_prototype.kicad_pcb, pn_wing_prototype.sch]
2020-08-24 work on routing phase noise downconverter
    [adc.sch, isolator.sch, pn_wing_prototype.kicad_pcb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]
2020-08-25 layout of phase noise downconverter
    [adc.sch, lo_amp.sch, pn_wing_prototype.kicad_pcb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]
2020-08-27 all nets connected in layout
    [isolator.sch, pn_wing_prototype.kicad_pcb, pn_wing_prototype.sch]
2020-08-28 finished silkscreen cleanup, added via stitching
    [pn_wing_prototype.kicad_pcb]
2020-08-28 added bottom layer ground plane, via cleanup
    [pn_wing_prototype.kicad_pcb]
2020-08-28 drc and erc check, schematic cleanup
    [isolator.sch, lo_amp.sch, pn_wing_prototype.kicad_pcb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]
2020-08-29 checked stability of LO amplifier, started migen project, added more flexibility for active filtering on baseband path
    [adc.sch, lo_amp_stability.sch, pn_wing_prototype.kicad_pcb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]
2020-08-29 final layout cleanup, ordered phase noise downconverter boards
    [pn_wing_prototype.kicad_pcb, power.sch, synth.sch]
2020-08-30 added part numbers to schematic of phase noise downconverter, ordered
    [adc.sch, isolator.sch, lo_amp.sch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]
2020-09-05 added assembly drawing
    [adc.sch, pn_wing_prototype.kicad_pcb]
2020-09-15 start testing cic filter
2020-09-16 added schematic export, updated README, schematic cleanup
    [pn_wing_prototype.sch, ref_pll.sch, rf_path.sch]
2020-09-16 Updated README to point to schematic
2020-09-17 corrected wiring on ddc..
2020-09-26 started on lmx2594 drivers
2020-09-27 commincation with on-board synth works, fixed spi and fpga pin mapping
    [ecp5_evn.py, main.c]
2020-10-18 fixed rectifier circuit, inverted first lna to cancel out inverting integrator..
    [ref_pll.sch, rf_path.sch]
2020-10-25 fix integrator in reference pll..
    [ref_pll.sch]
2020-10-30 updated schematic export with pll fix
    [pn_wing_prototype.sch]
